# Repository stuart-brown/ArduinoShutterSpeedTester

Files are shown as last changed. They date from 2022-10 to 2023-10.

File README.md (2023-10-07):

# Arduino Shutter Speed Tester

A project to build a shutter speed tester using KY-008 laser diodes, ISO203 Laser Receiver & TFT display, all driven by an [Arduino Nano](https://docs.arduino.cc/hardware/nano). The code was developed in [VSCode](https://code.visualstudio.com/) using [Platform IO](https://platformio.org/). 
<br>

<div style="text-align: center;">
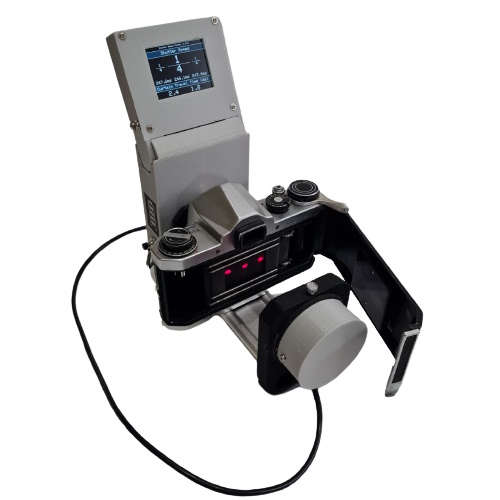
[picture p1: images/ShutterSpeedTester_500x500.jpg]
Shutter Speed Tester

</div>

## Status
This is a work in progress.
<br>

### What works:
* Measurement of shutter speeds & curtain travel times using 3 lasers and sensors
* Display time measurements & corresponding fractional shutter speeds  
* Display curtain travel times for 1st & 2nd curtain
* Calibration check
<br>

### To do:
* More content in this Readme, especially about calibration
* Ability to measure cameras like Barnack Leicas where you cannot access the rear of the shutter curtain.
* Finish project documentation: references, datasheets, circuit diagrams, etc. 
<br>

## Wiring Diagram
<div style="text-align: center;">
Wiring Diagram
</div>

## Components
### Arduino Nano
The heart of the system is an Arduino Nano.
<div style="text-align: center;">
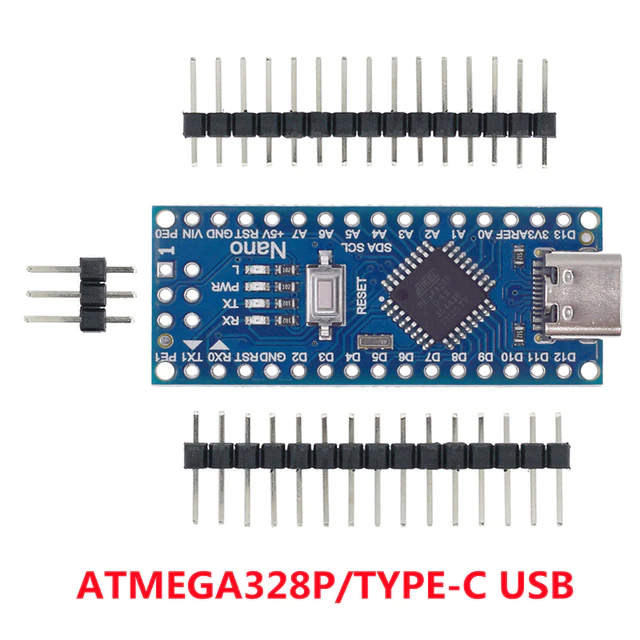
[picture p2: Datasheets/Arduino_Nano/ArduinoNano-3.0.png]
Arduino Nano

</div> 

### Laser Diode
The [KY-008 laser diode](https://arduinomodules.info/ky-008-laser-transmitter-module/) is a 650nm (red) laser, with an output power of 5mW. It can be bought as a standalone component or in module form (KY-008). The documentation says it can operate off of 5V, but reports on the internet say it will burn out quickly and a 39 ohm series resistor is needed to drop the voltage. The module version contains this resistor. This is what it looks like:
<div style="text-align: center;">
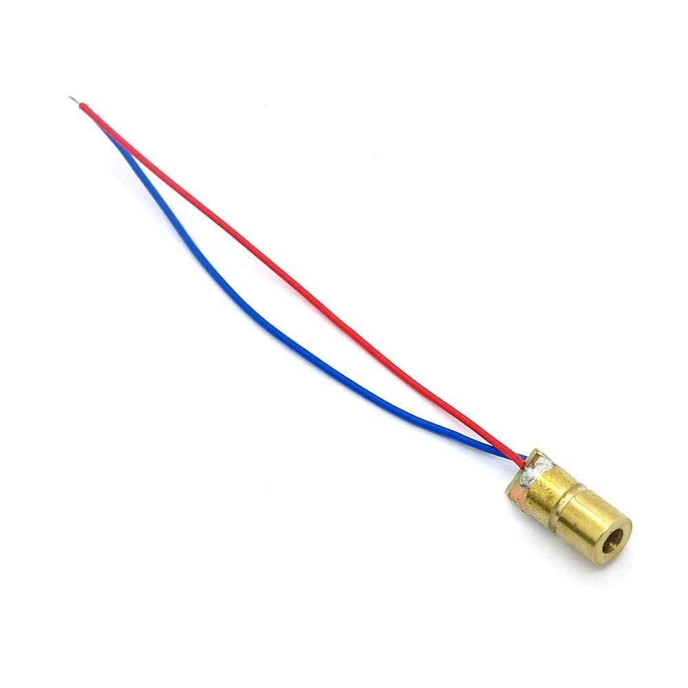
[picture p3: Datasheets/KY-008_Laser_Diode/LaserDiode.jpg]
Laser Diode (Standalone)

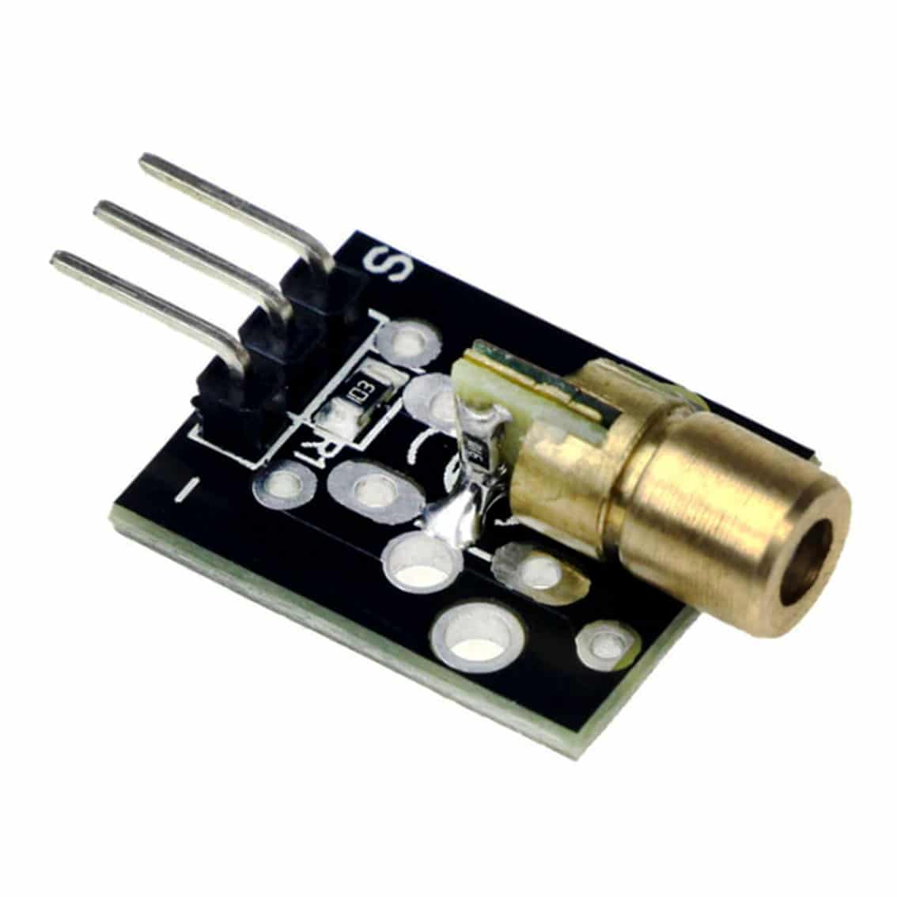
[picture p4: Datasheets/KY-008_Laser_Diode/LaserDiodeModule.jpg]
Laser Diode (Module)

</div>

### ISO203 Laser Receiver
It was difficult to find information on this component, but fortunately I came across a good [blog post](https://www.codrey.com/electronic-circuits/the-mysterious-laser-receiver-sensor-module/) covering it. It can be bought as a laser sensor module, or a standalone laser receiver. The module contains the components needed so you can simply plug it in to your Arduino. If you use the stand alone receiver, a pull-up resistor on the signal leg is needed.  This is what it looks like:
<div style="text-align: center;"> 
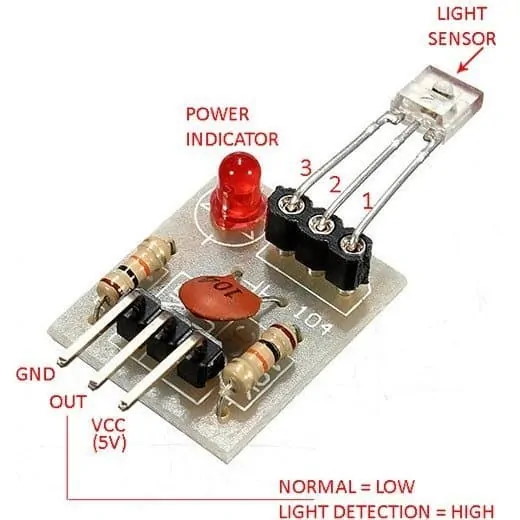
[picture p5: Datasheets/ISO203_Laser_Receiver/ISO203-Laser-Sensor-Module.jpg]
Laser Sensor Module

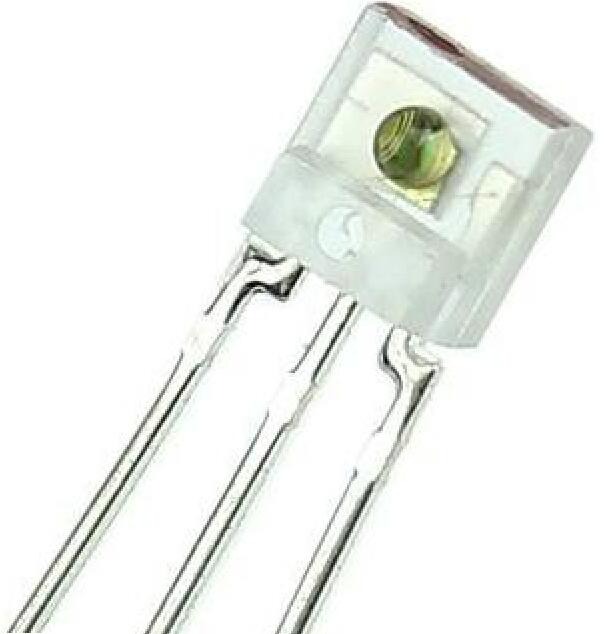
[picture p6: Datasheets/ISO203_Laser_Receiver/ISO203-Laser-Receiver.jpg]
Laser Receiver
 
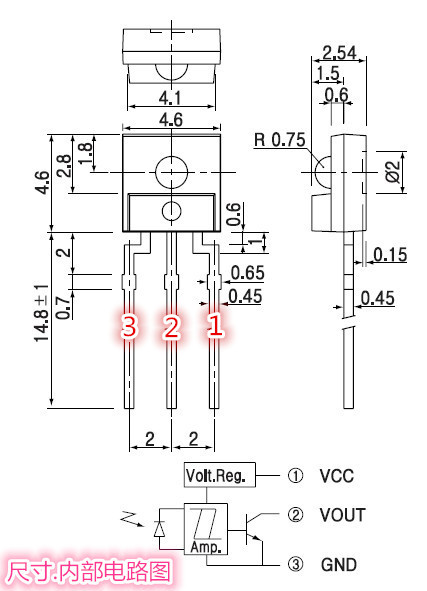
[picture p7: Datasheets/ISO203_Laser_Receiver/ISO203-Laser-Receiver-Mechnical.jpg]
Laser Sensor Module

</div> 

### LiPo Charger / Voltage Regulator Module
This module charges the LiPo battery and provides a constant regulated voltage to the Arduino and other electronics.
<div style="text-align: center;">
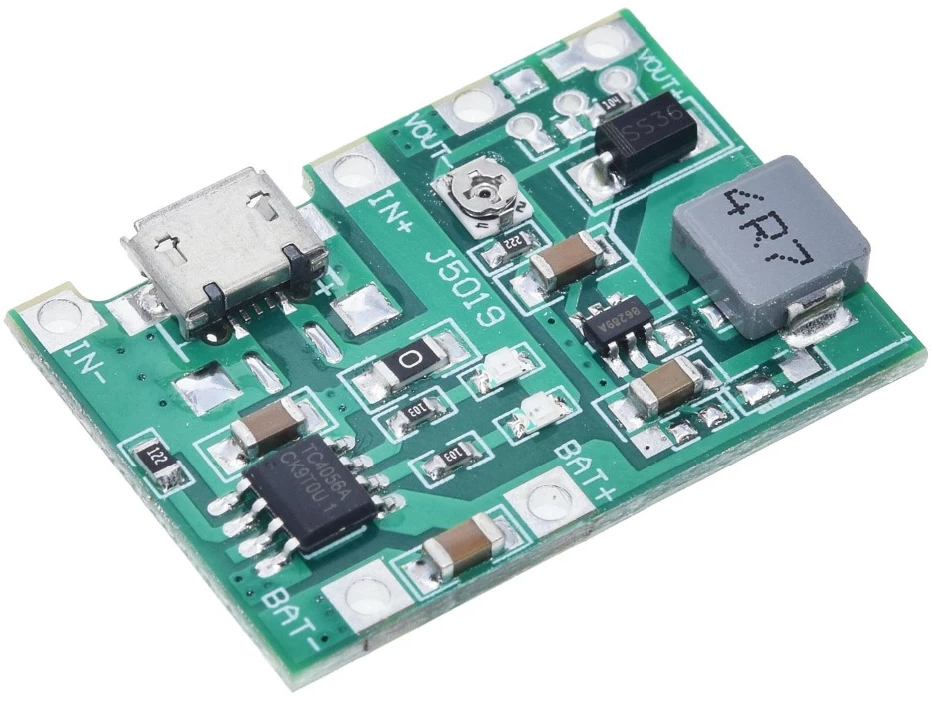
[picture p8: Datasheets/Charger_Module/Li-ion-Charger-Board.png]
LiPo Module

</div> 

### TXS0108E 8 Channel Level Shifter
The Arduino uses 5V logic levels, but the TFT display requires 3.3V levels. A level shifter is needed between the Arduino and the TFT display.
<div style="text-align: center;">
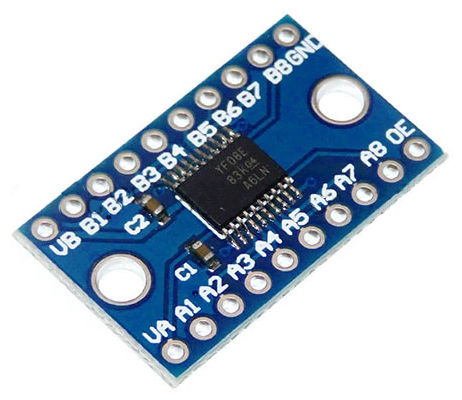
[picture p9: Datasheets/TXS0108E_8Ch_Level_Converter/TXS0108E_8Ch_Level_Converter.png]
TXS0108E Level Shifter

</div> 

### Display
The project started with a small 0.96 inch OLED display. But it was too small, so it was replaced by a larger TFT LCD.

##### 0.96" OLED 
 The code for the OLED display is still in the code base, it can be enabled by changing the line `#define USE_OLED 0` to `#define USE_OLED 1`. The OLED uses the i2c interface, and this is not shown on the wiring diagram.
<div style="text-align: center;">
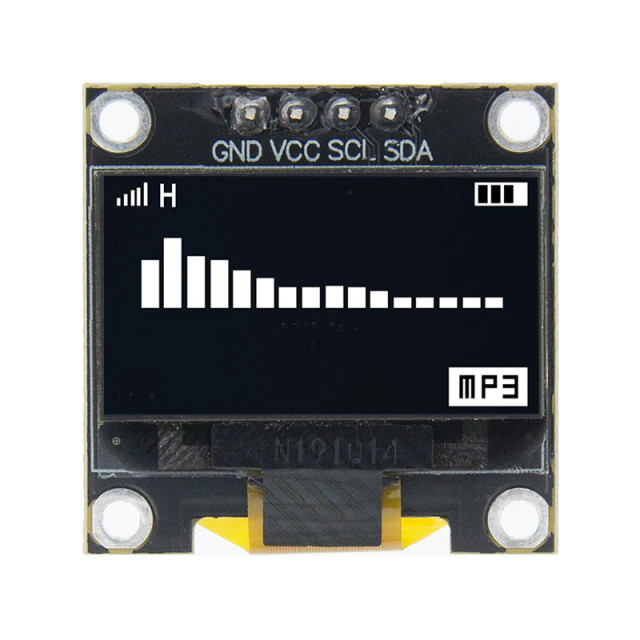
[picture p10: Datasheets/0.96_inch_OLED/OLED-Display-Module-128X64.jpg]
Small OLED Display

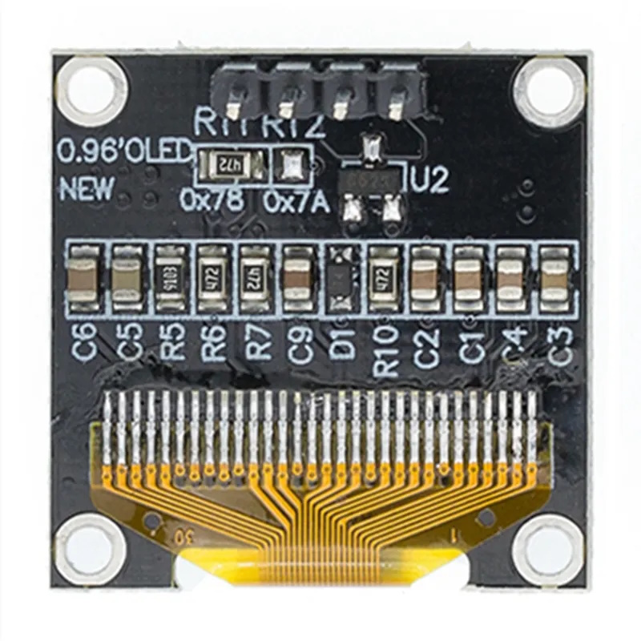
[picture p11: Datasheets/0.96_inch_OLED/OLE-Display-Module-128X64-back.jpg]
Small OLED Display
  
</div> 

##### TFT LCD Display
The tester was built using a 2.2 inch TFT display with 240x320 resolution and ILI9341 driver chip. A smaller or larger display could be used as long as the resolution and driver are the same. The display used had a SD Card slot on the back, this was was not used.
<div style="text-align: center;">
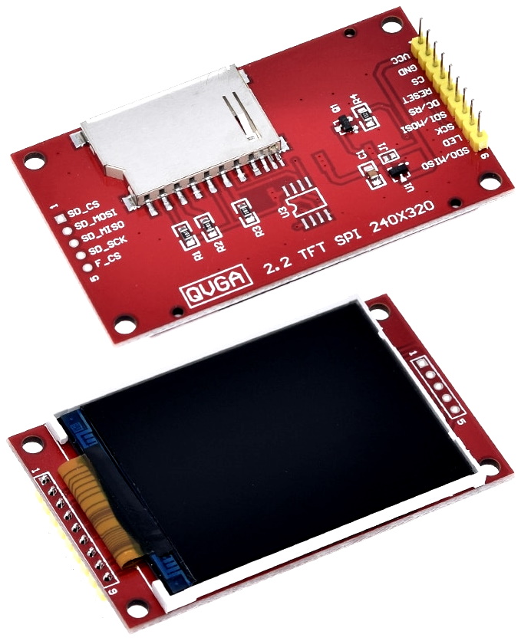
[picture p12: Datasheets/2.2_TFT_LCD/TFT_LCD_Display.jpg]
TFT LCD Display

</div> 
<br>

### Other components
Rocker switch, USB charge connector and a 550mAh 13400 battery recovered from a disposed vape. The second version added a battery indicator and normally open momentary push button to connect it to the battery to show the battery level.
<div style="text-align: center;">
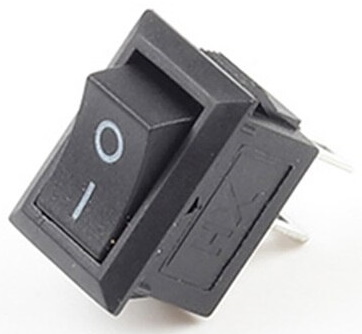
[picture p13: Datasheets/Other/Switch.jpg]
Switch

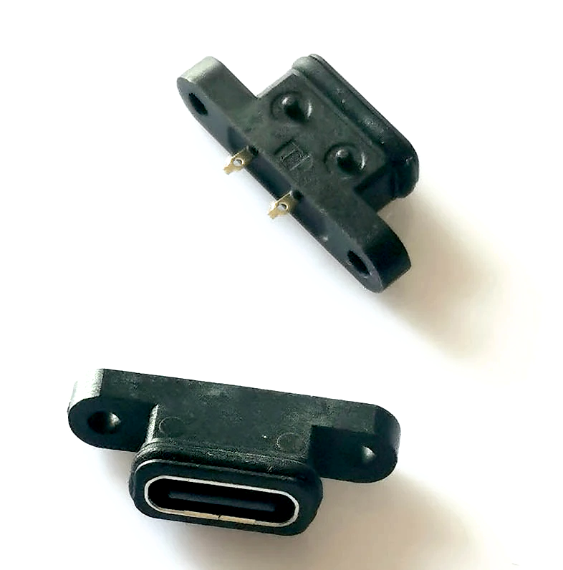
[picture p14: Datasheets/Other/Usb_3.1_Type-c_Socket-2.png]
USB Power Socket

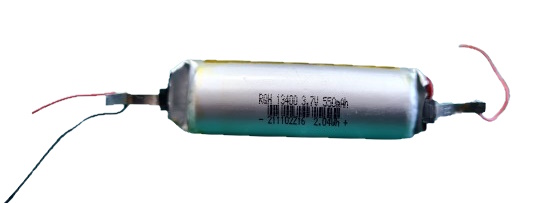
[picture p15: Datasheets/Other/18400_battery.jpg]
18400 Battery

</div>
<div style="text-align: center;">
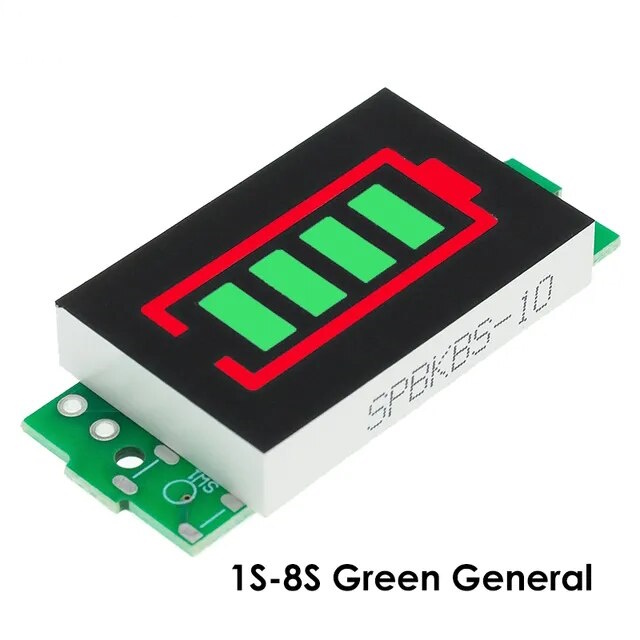
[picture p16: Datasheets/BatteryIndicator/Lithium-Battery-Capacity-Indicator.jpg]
Battery Indicator

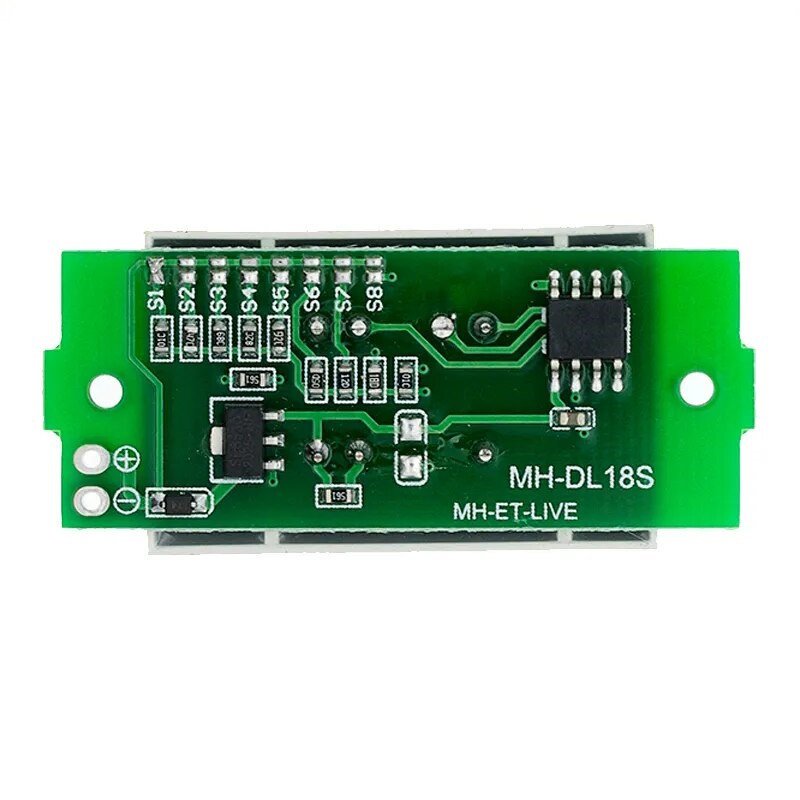
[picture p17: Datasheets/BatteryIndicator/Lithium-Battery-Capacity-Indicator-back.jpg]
Battery Indicator

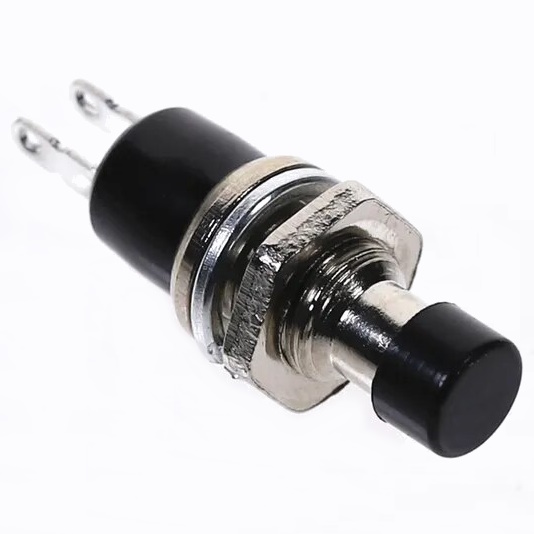
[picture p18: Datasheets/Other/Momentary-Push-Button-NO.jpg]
NO Momentary Push Button

</div>

<br>

## Mechanicals
The mechanical build is based on a Pangor M42 macro bellows, paired with 3D printed parts. The design could be adjusted to work with any bellows. 

The bellows was disassembled to remove the expanding bellows and only the rail and end housings were used. This forms the chassis to which the 3D printed parts attach. There are two housings attached, one at either end of the chassis. There is one for the laser detectors and electronics, and another for the laser diodes. Both the laser diode and laser sensor housings are circular and can be rotated to allow the sensors and lasers to be aligned. Using a macro bellows as the chassis provides a stable platform that makes sensor and diode alignment easy and keeps them aligned when sliding further apart or closer together to accommodate different cameras.

The laser detectors are kept close to the electronics to minimise the chances of false detects due to noise. 

Since the laser diodes only need power to turn them on, noise is not an issue, and they are on the end of a cable that connects them to the electronics box.

<div style="text-align: center;">
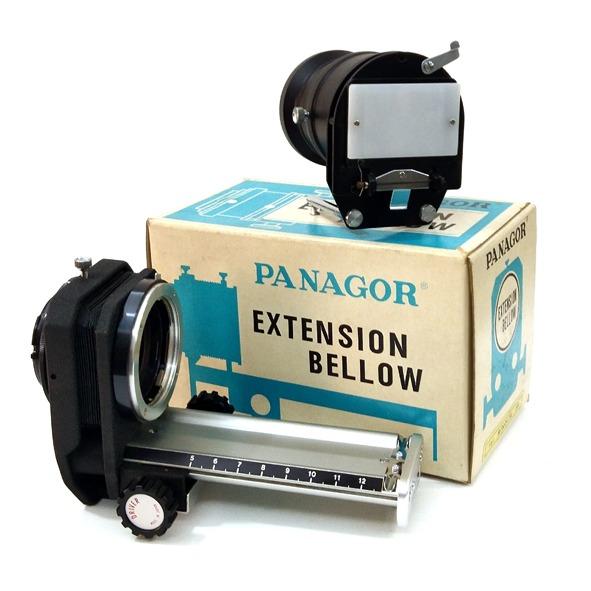
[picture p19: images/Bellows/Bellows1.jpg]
Pangor M42 Macro Bellows

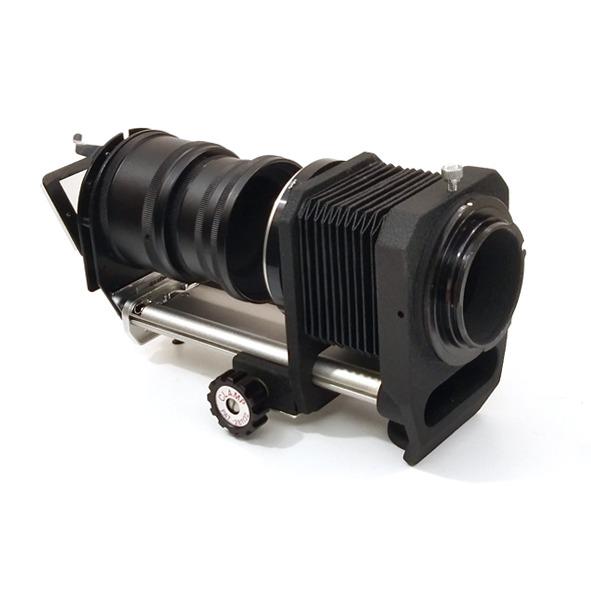
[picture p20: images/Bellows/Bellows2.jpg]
Pangor M42 Macro Bellows

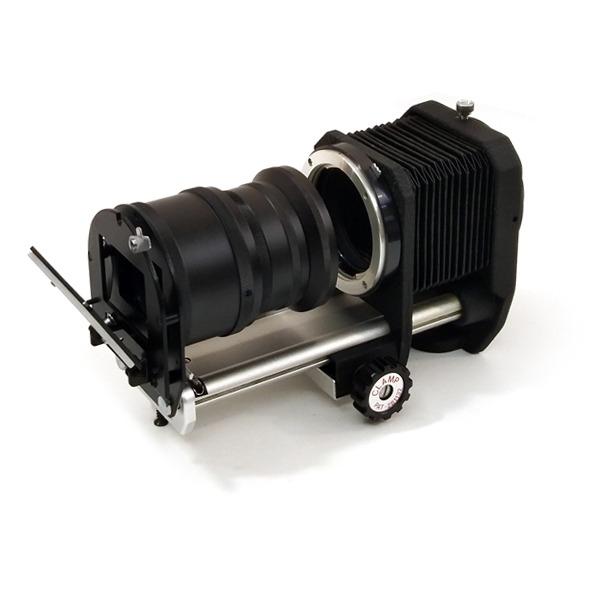
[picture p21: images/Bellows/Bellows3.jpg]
Pangor M42 Macro Bellows

</div>

Construction photos showing details of the assembly are shown below. More photographs are available in the images directory of the project.

### Version 1
<div style="text-align: center;">
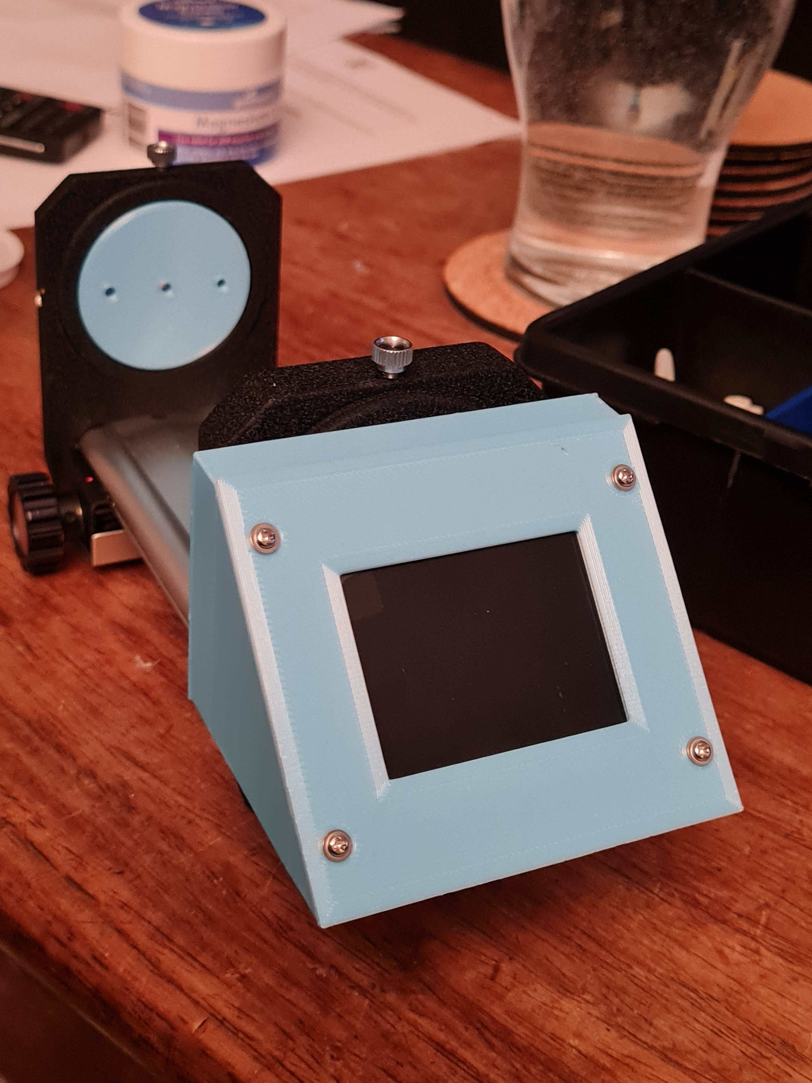
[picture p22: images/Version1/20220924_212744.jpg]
Version 1

</div>
<br>

Version 1 of the housing was printed using blue PLA and coloured black using a liquid shoe dye. Once built it became evident that there were a few deficiencies in the design:
1) The laser diode holders were printed with three small screws at 120 degree intervals. The idea being that the screws could be used to hold the laser diodes and adjusted to aim the diode at the sensor. This idea did not work.
2) The screen was awkward to read, it needed to face the other direction.

#### Laser diodes
An old USB cable with a broken connector was used to connect the laser diodes. Both end connectors were cut off and each laser diode wired to one wire connected to an IO pin on the Arduino. A common ground was wired on the 4th wire. The current limiting resistors are soldered inline, directly between the diode and wire, covered in heat shrink to prevent shorting. A simple knot in the cable serves as strain relief.

<div style="text-align: center;">
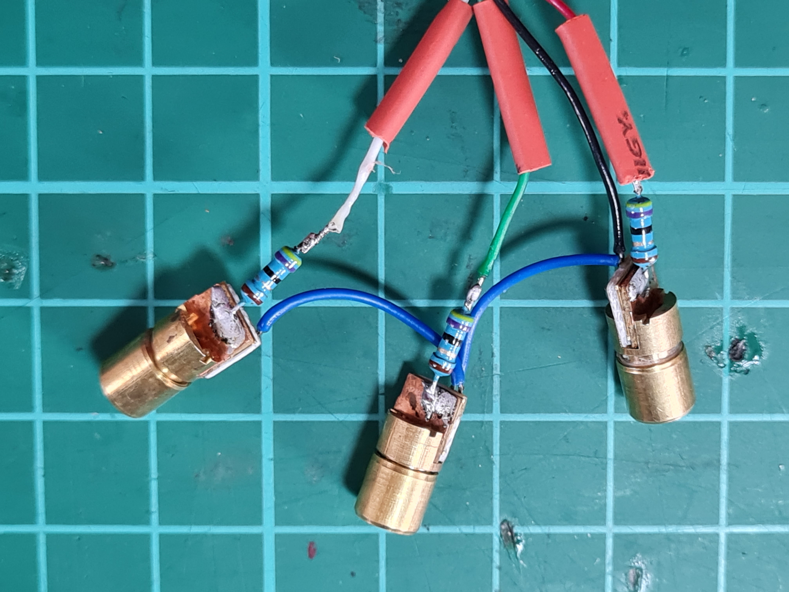
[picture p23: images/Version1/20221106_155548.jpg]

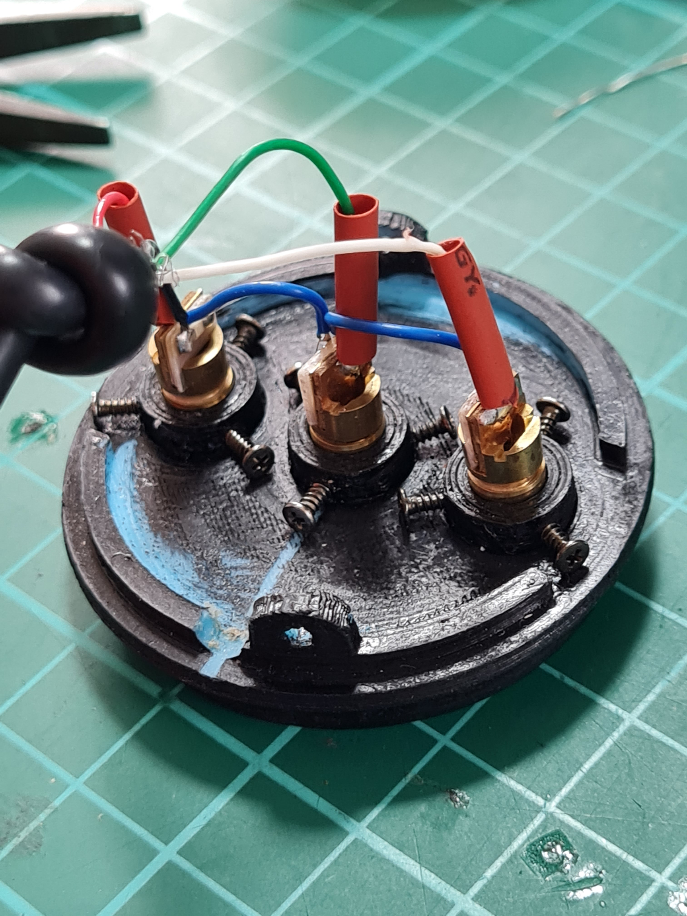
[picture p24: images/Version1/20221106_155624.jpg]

</div>

#### Laser sensors
Each laser sensor is soldered onto a small piece of [stripboard](https://en.wikipedia.org/wiki/Stripboard) with its 10kΩ pull up resistor. They fit into specially shaped recesses on the 3D printed part and are held in place by a plate that clamps down on the back of them. They are wired with common ground and power lines, and each has its own signal line to an IO pin on the Arduino.

<div style="text-align: center;">
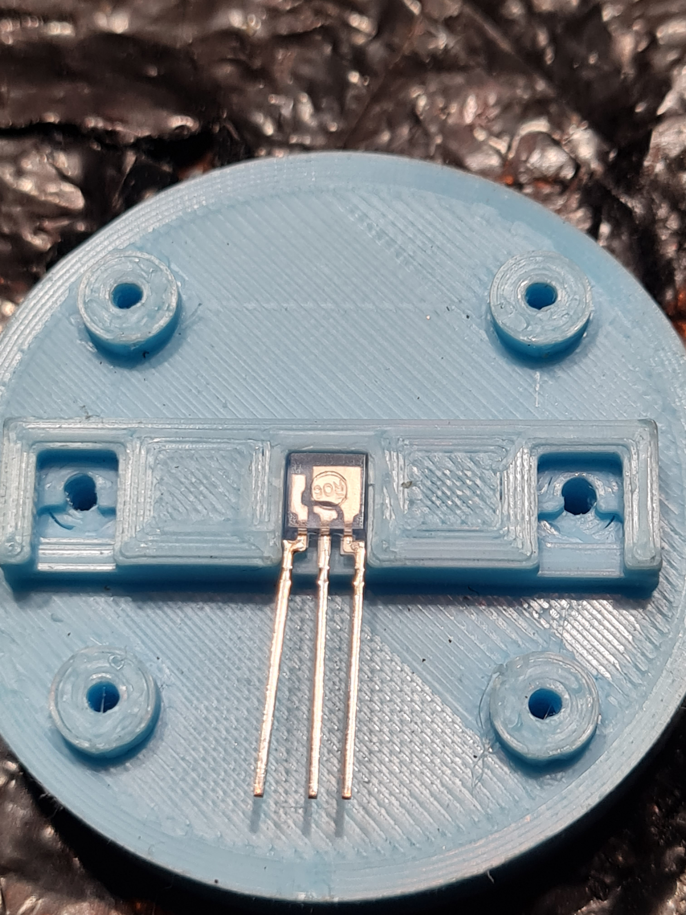
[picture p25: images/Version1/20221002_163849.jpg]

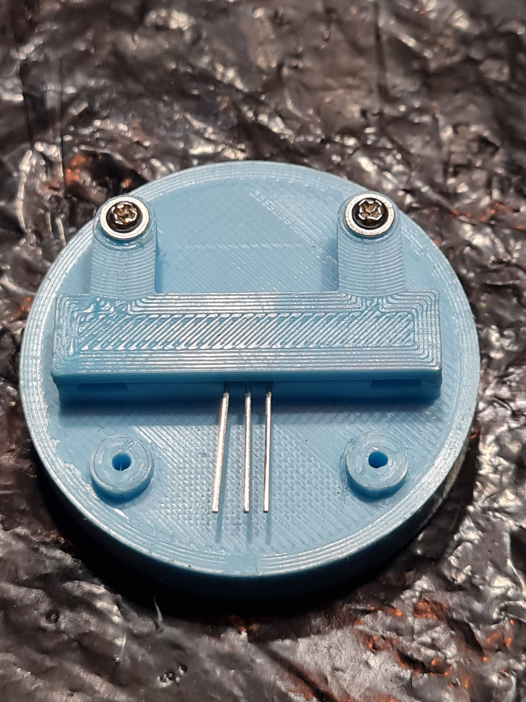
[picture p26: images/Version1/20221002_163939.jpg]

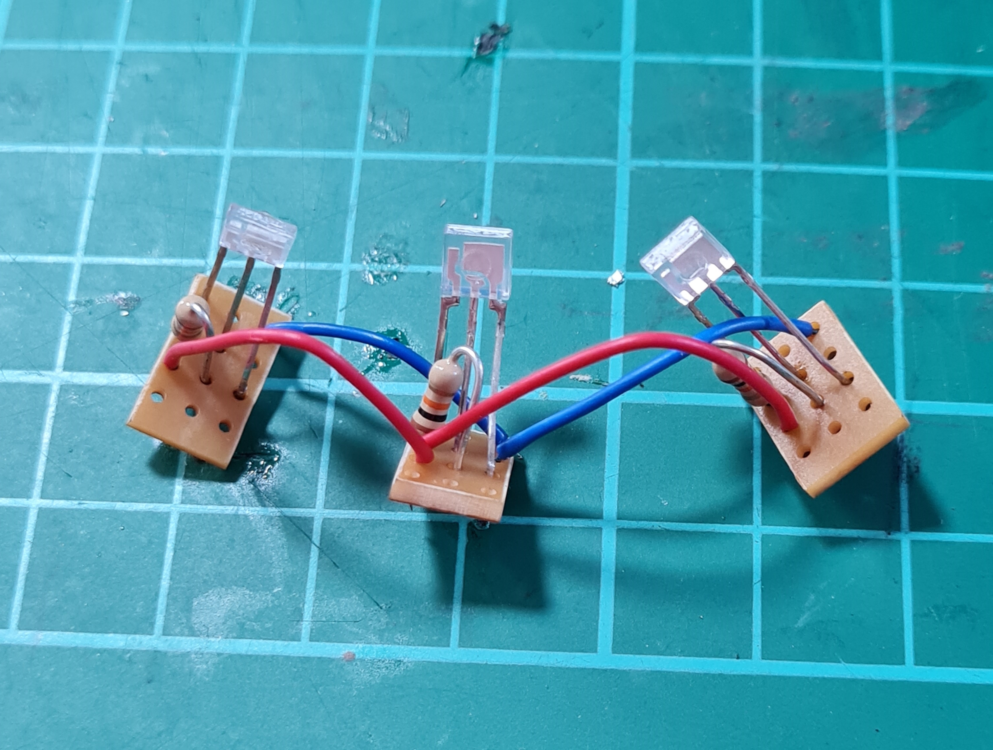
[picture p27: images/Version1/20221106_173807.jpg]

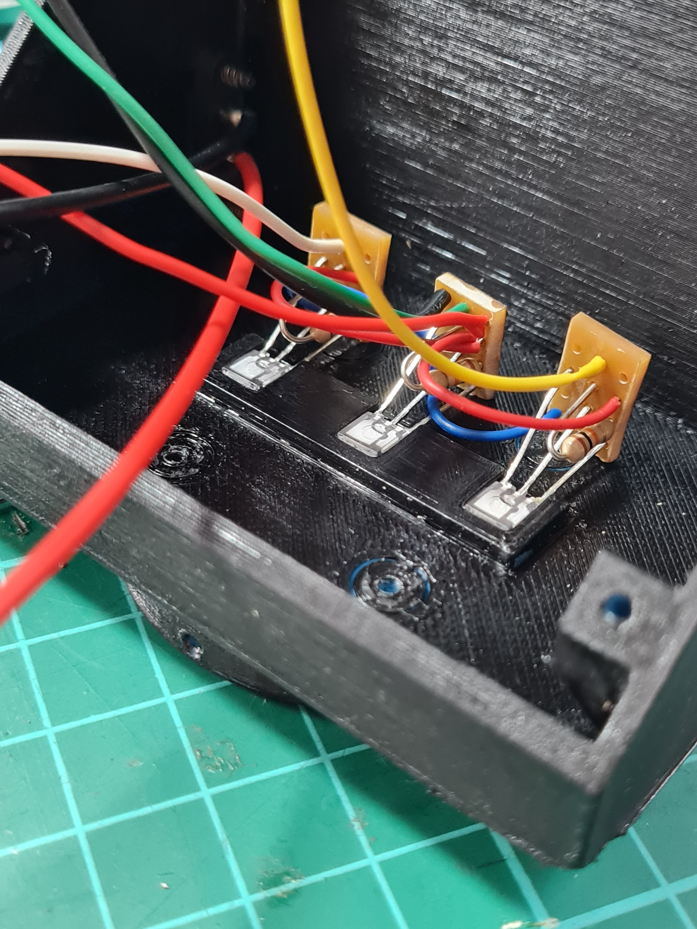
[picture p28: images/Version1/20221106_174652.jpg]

</div>

<br>

#### Display and electronics
The display and electronics are housed in a box that mounts to the laser detector housing. It was rather tight in this version.

<div style="text-align: center;">
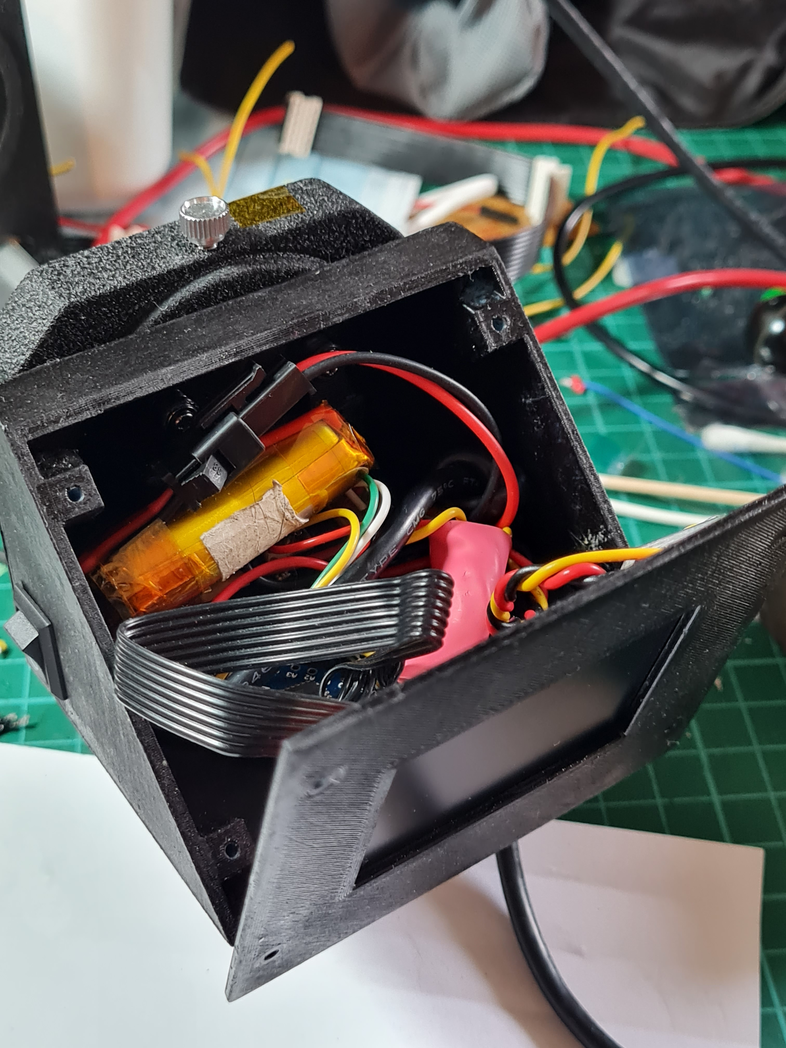
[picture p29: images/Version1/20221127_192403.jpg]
Display and electronics

</div>

#### Alignment
The macro bellows has two thumb screws, one on each side (red arrows in image below). The laser detector housing has a 3D printed "dimple" in the circular ring at the "12 o'clock" position that the thumb screw screws into to align it and stop it rotating. The laser diode holder does not have any "dimples", it can be rotated to align the laser diodes and sensors (yellow arrow in image below), then the thumb screw is screwed down to hold it in place.  

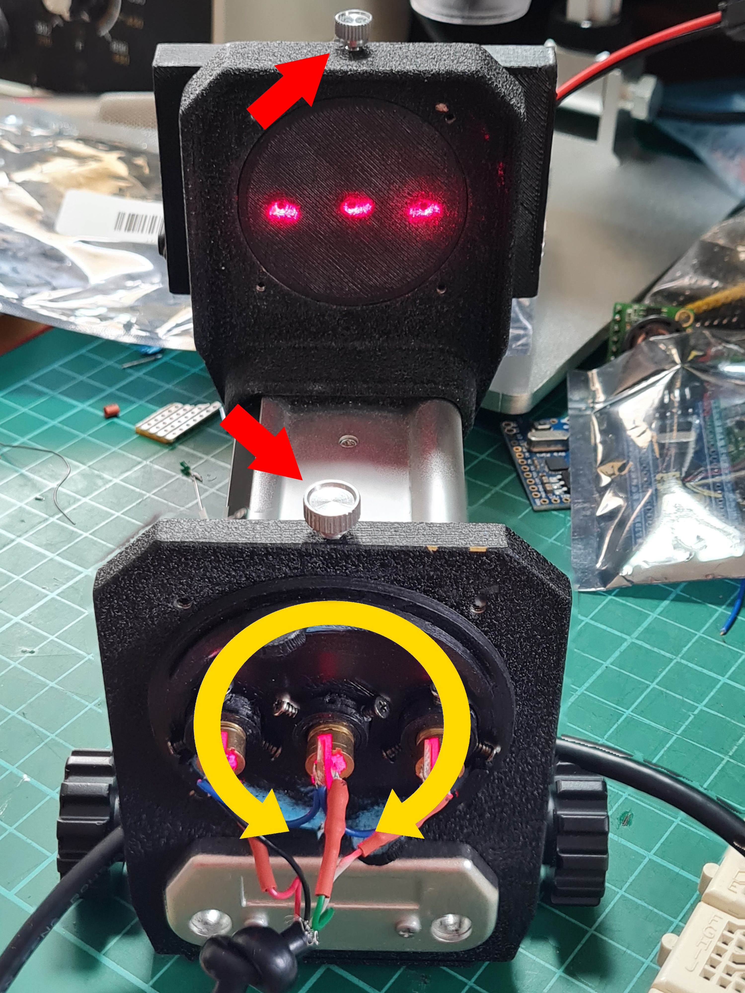
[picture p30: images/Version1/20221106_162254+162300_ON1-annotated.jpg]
Alignment


### Version 2
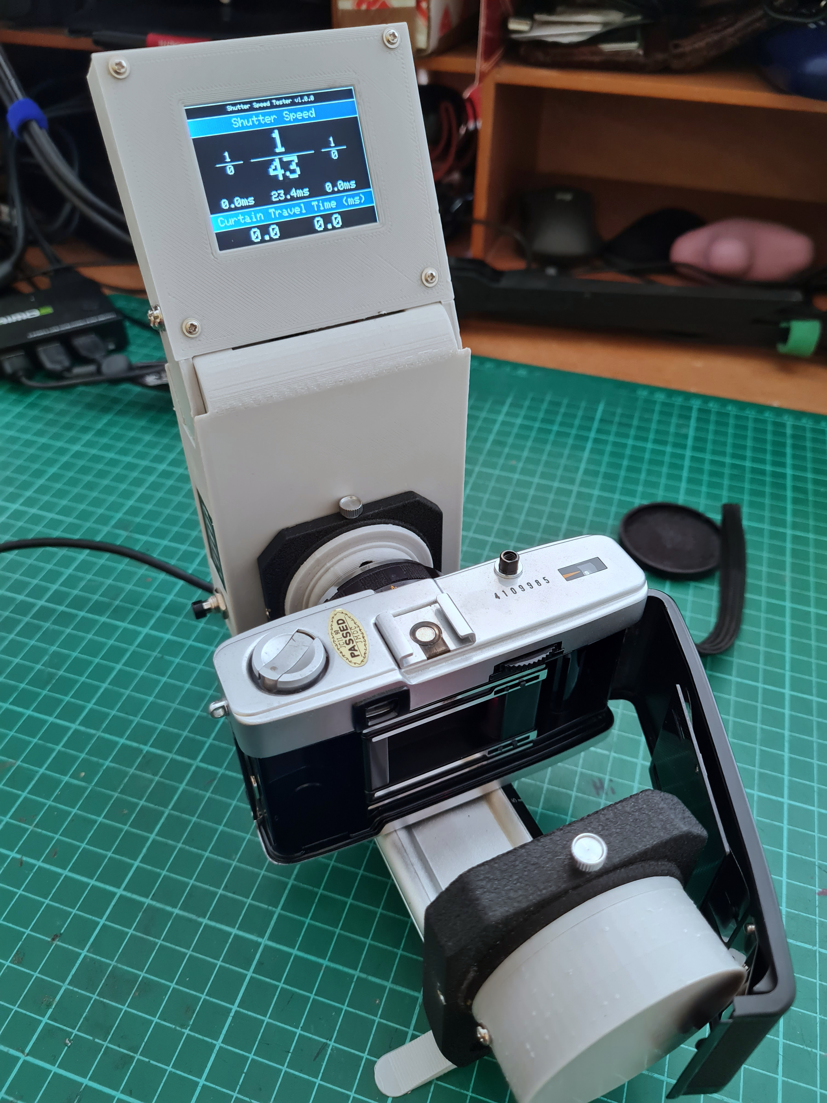
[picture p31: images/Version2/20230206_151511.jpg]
Version 2

<br>

Version 2 of the housing corrected the issues with the first design and added a battery meter and some small improvements. A 3D printed foot was also added for stability. 

Version 2 also has some problems that will be corrected in the next version: 
 1) The display was designed to be adjustable, this turned out to be not necessary and just added complication.
 2) The housing could be made smaller.

#### Battery Meter
The battery meter turned out to be much larger than anticipated and the bottom housing needed to be made much larger. This did help with the tight fit compared to version 1, there is much more space and the electronics fit in much easier.

<div style="text-align: center;">
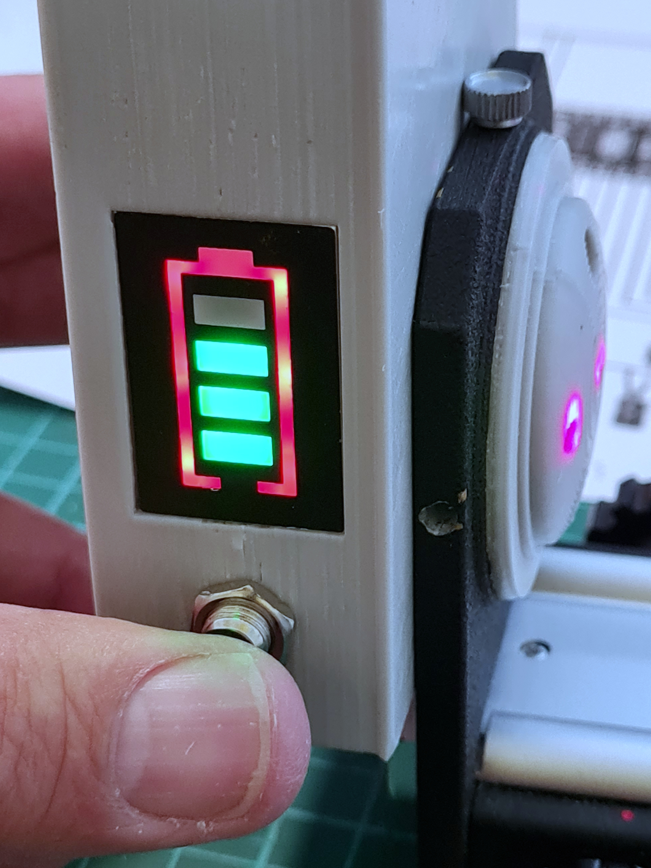
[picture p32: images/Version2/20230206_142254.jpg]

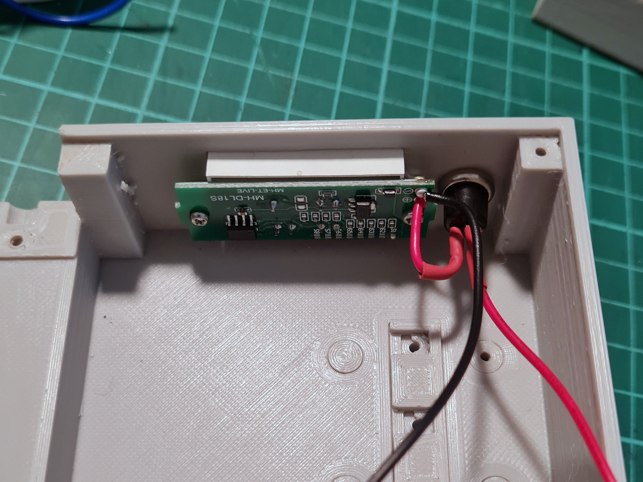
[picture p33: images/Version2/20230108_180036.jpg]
  
  </div>

#### Laser Diodes
The laser diodes are now housed in a ball joint, with each ball clamped down by a small rectangular block. This allow each laser to be adjusted and aimed at the corresponding laser sensor individually. The knot in the cable has been replaced by a proper cable strain relief block that clamps the cable.

<div style="text-align: center;">
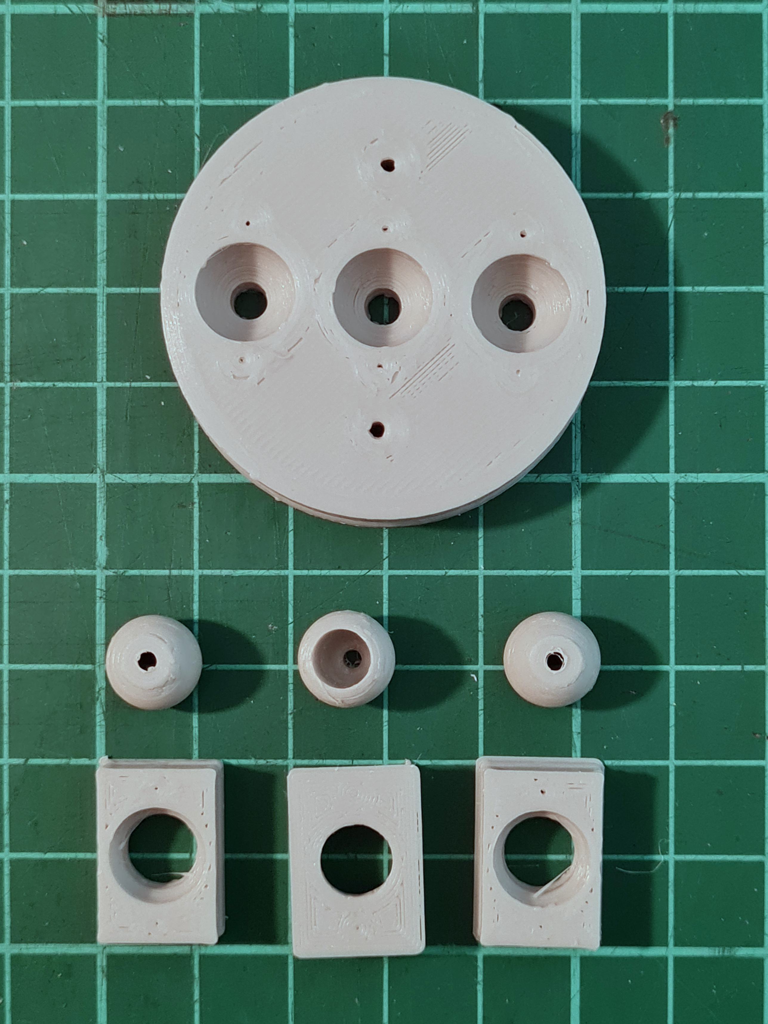
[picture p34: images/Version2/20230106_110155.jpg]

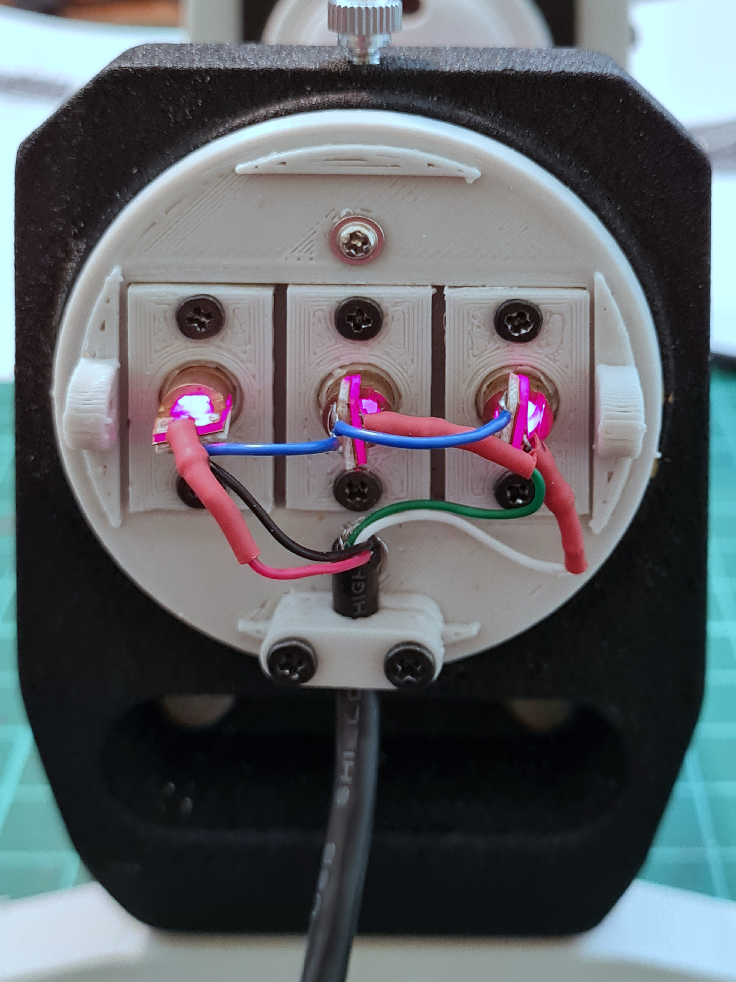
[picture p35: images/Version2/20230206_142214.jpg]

</div>
<div style="text-align: center;">
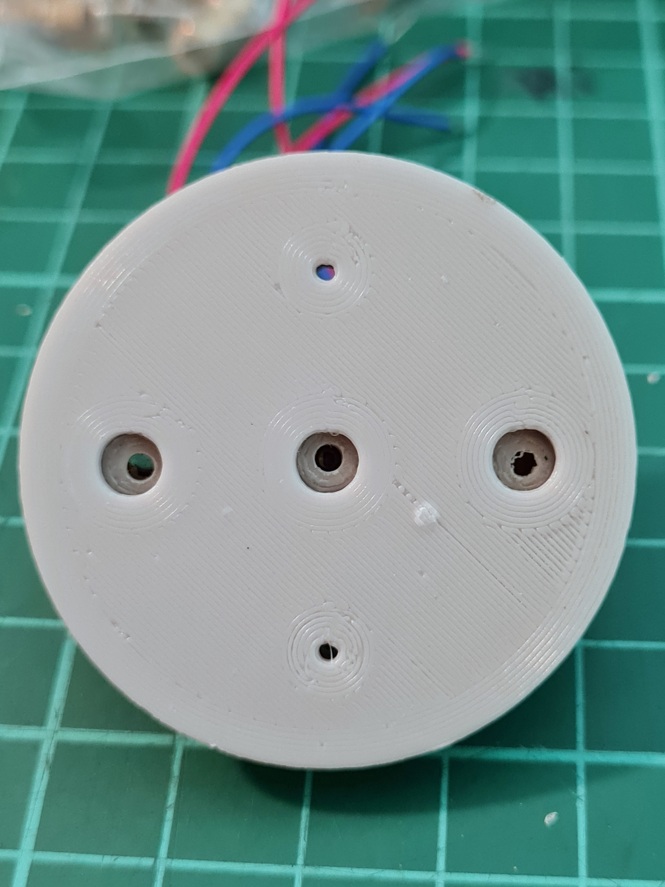
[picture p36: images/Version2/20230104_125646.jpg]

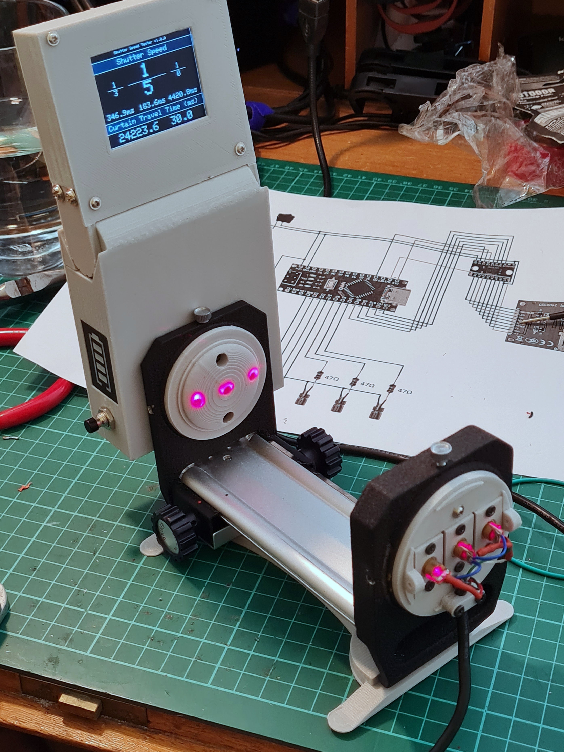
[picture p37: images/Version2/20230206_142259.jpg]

</div>

#### Camera Alignment Cone
A shallow cone screws onto the front of the laser detector housing. The camera lens mount ring is pushed onto this cone, and it helps to align the camera with the tester. 

<div style="text-align: center;">
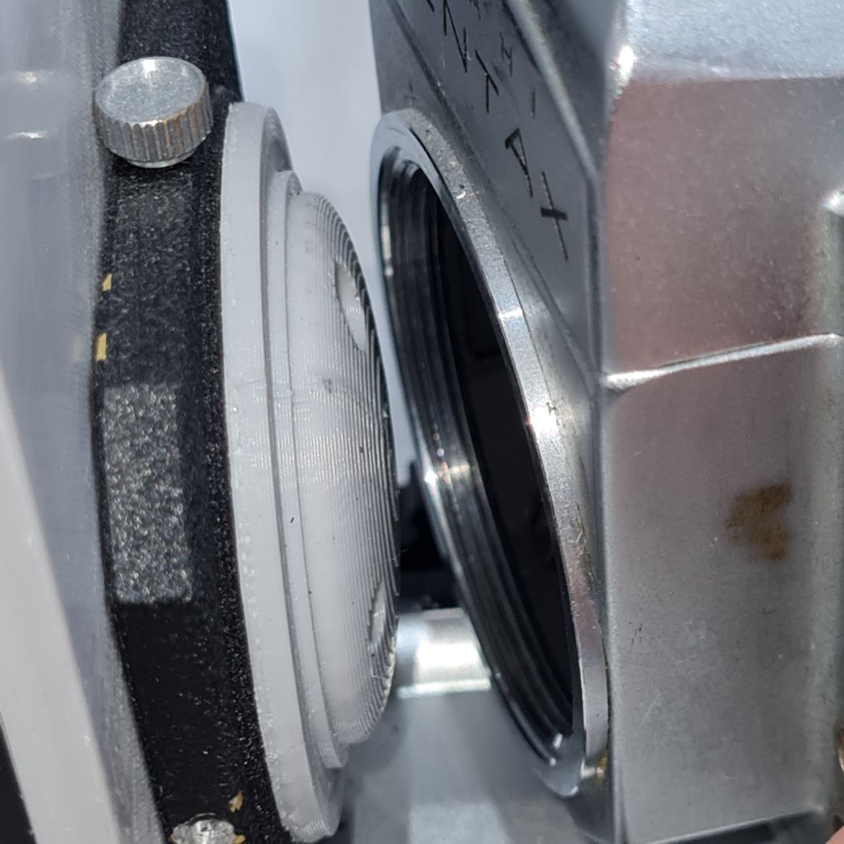
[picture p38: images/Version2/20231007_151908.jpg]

</div>

#### Foot
A 3D printed foot is bolted onto the tripod mount on the bottom of the bellows housing to improve stability.
<div style="text-align: center;">
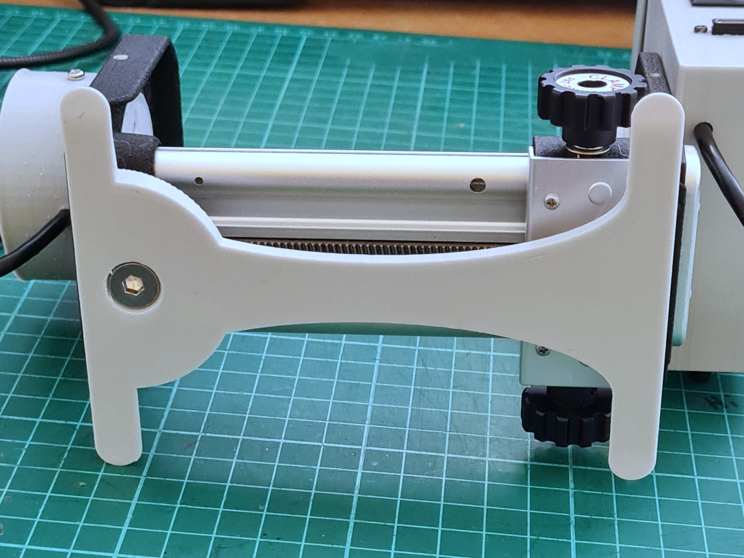
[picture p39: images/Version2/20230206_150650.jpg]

</div>
<br>

## 3D Printed Parts
The STL files for the 3D Printed parts can be found in the STL folder in the repository

# Getting Going
* Download and setup VSCode and PlatformIO. See https://dronebotworkshop.com/platformio/
* Open the project in VSCode
* Build using PlatformIO
<br>

# Calibration
Calibration was done using a calibration device consisting of a STM32 Nucleo-F303RE development board driving a KY-008 laser diode. This pulses the laser at regular intervals, the width of the pulse can be changed by pressing the 'user' button on the dev board. The width of the ON pulses was measured using a digital storage oscilloscope to confirm their accuracy.

The STM32 calibration device was then use to illuminate the laser receiver on the shutter speed tester to check that the tester measured and displayed the correct time.

The rise and fall times of the laser detector were also checked using the oscilloscope.

Details of the calibration device can be found in the following repo https://github.com/stuart-brown/ShutterSpeedTesterCalibrator

<br>

# References and Interesting Reading:
* [ISO 516:2019 Camera shutters — Timing — General definition and mechanical shutter measurements](https://www.iso.org/standard/70966.html) - This is __*the standard*__ for testing shutter speeds. You need to buy the standard, but there are various previews available online, enough to glean useful information from.

* [The Way to Modern Shutter Speed Measurement Methods A, Historical Overview, by Gyula Simon, Gergely Vakulya, and Márk Rátosi](https://www.mdpi.com/1424-8220/22/5/1871) - A paper that delves into various methods to measure shutter speeds.

* [National Camera, Technician Course, Testing Shutter Speeds](https://learncamerarepair.com/downloads/pdf/NatCam-Shutter-Test-Guide.pdf)

* [Charts of Nominal, and Precise Actual camera
Shutter speed, f stop and ISO goal values](https://www.scantips.com/lights/math.html) &  [Camera Math of photography settings and EV](https://www.scantips.com/lights/fstop2.html) - These pages contain an enlightening discussion about 'Nominal' vs 'Accurate' values and the maths behind cameras.

<br>
<br>

# Some other shutter speed testers & projects
* http://forum.mflenses.com/the-shutter-speed-meter-project-t11387.html

* https://www.pentaxforums.com/forums/8-film-slrs-compact-film-cameras/409300-optical-measurements-pentax-me-super-shutter-speed.html

* https://www.pentaxforums.com/forums/173-general-photography/359823-true-shutter-speeds-compared-nominal-shutter-speeds-actual-measurements.html

* [Laser Shutter Tester](https://community.element14.com/challenges-projects/project14/makingtime/b/blog/posts/laser-shutter-tester)

* [VFMOTO camera shutter tester](https://www.ebay.com/usr/vfmoto) - A commercial product sold on EBay

* [Film Camera Tester](https://github.com/srozum/film_camera_tester/wiki) - This one is available as a DIY kit on or assembled from [Tindie](https://www.tindie.com/products/srozum/film-camera-tester/)

* [Speed tester](https://github.com/cameradactyl/Shutter-Timer) by cameradactyl - A project very similar to this one :)

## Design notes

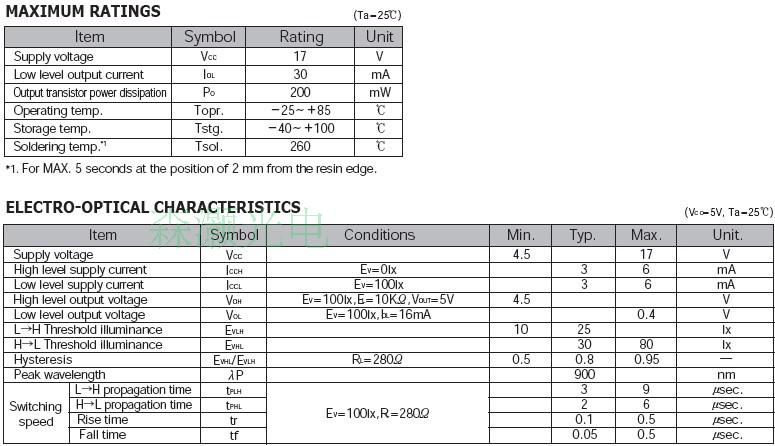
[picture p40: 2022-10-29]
Datasheets/ISO203_Laser_Receiver/ISO203-Laser-Receiver-Specification-1.jpg

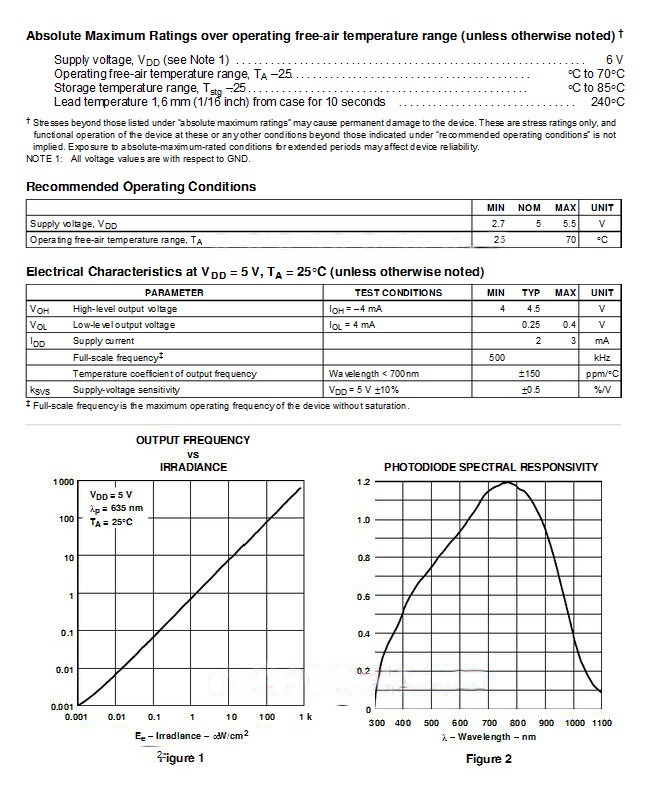
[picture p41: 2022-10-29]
Datasheets/ISO203_Laser_Receiver/ISO203-Laser-Receiver-Specification-2.jpg

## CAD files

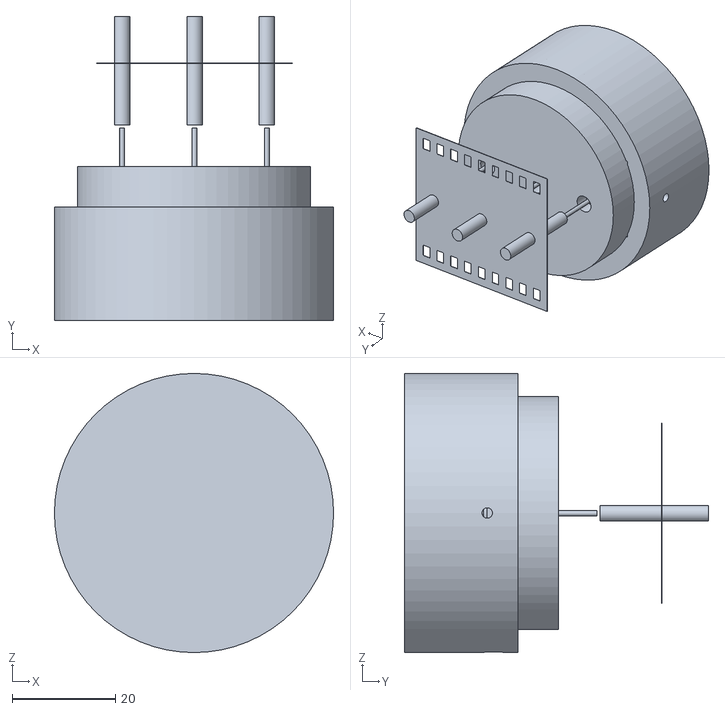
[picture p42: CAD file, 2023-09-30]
STL/Version2/Laser Diode Holder v2 Assembly.stl
54.0 x 58.8 x 54.0

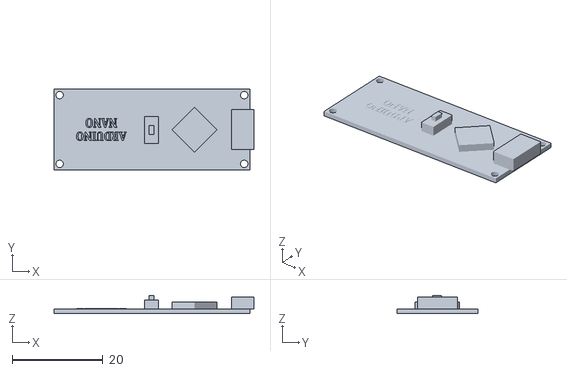
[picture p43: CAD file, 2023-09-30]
STL/ElectronicComponents/Arduino Nano.stl
44.1 x 17.8 x 4.00

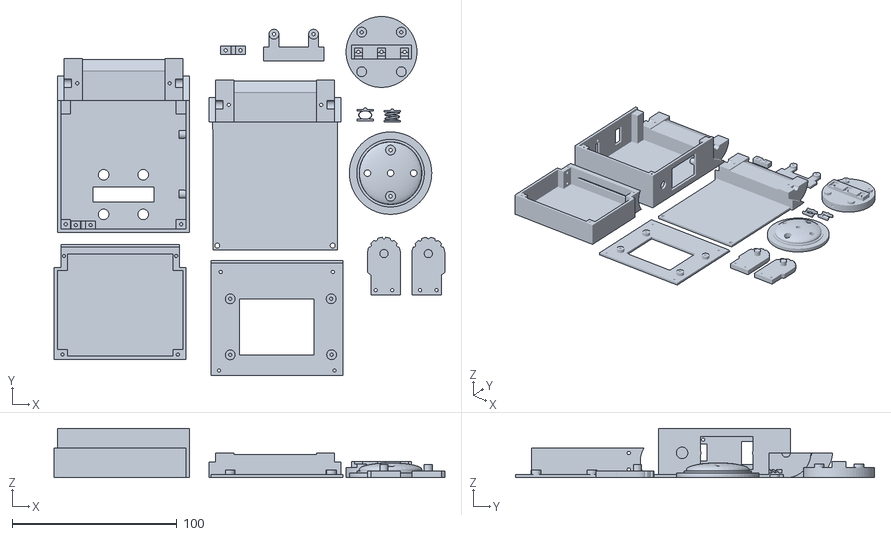
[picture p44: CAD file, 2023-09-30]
STL/Version2/Electronics Box v2.stl
236.9 x 217.7 x 30.0

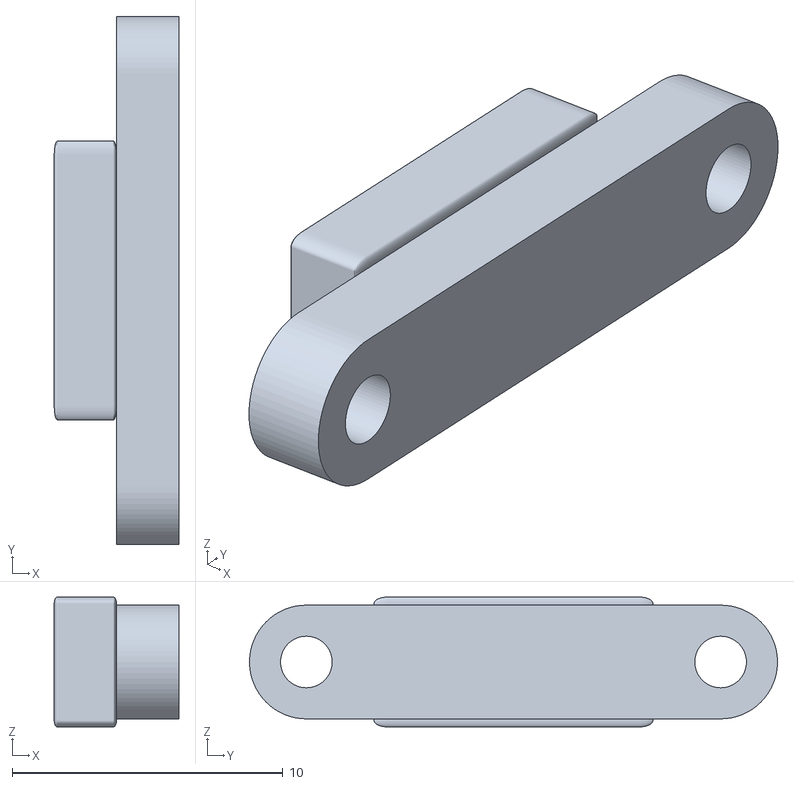
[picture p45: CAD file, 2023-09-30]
STL/ElectronicComponents/USB-C Charging Connector.stl
4.60 x 19.5 x 4.80

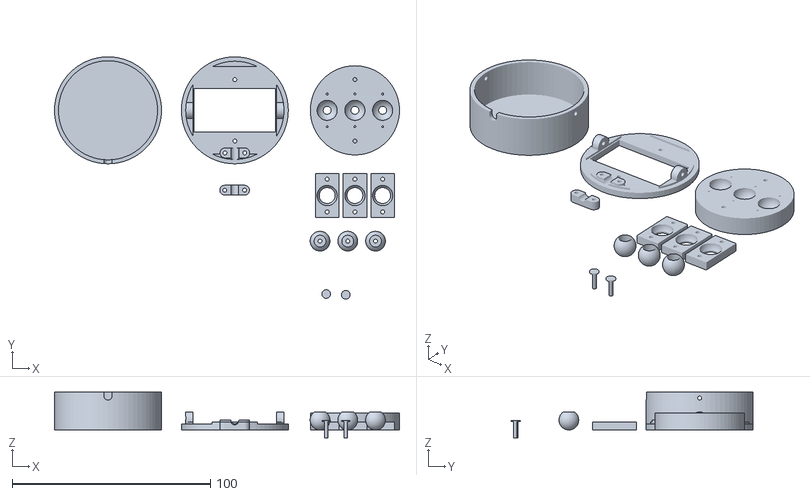
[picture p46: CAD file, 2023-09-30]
STL/Version2/Laser Diode Holder v2.stl
174.1 x 122.3 x 23.1

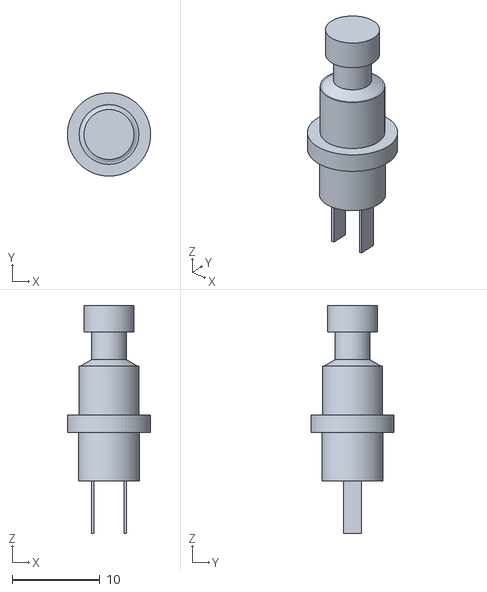
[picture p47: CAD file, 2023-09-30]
STL/ElectronicComponents/Push Switch.stl
9.50 x 9.50 x 26.0

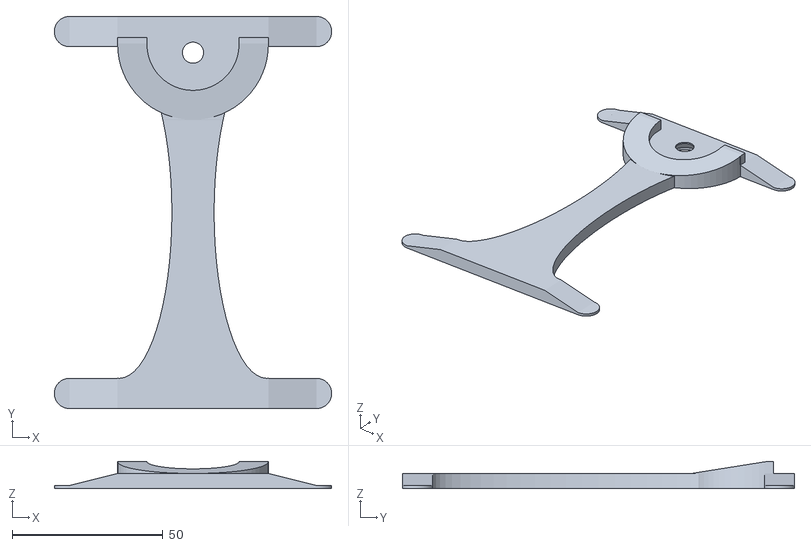
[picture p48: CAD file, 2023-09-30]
STL/Version2/Shutter Tester Stand.stl
92.0 x 130.0 x 9.00

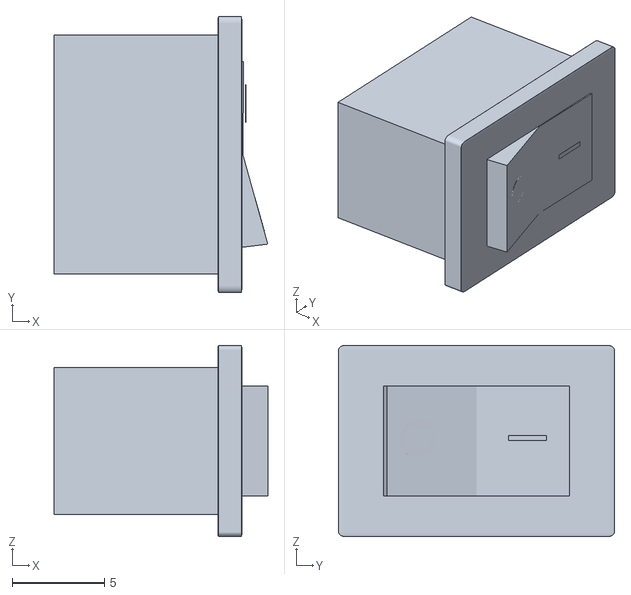
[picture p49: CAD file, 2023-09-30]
STL/ElectronicComponents/Rocker Switch.stl
11.6 x 15.0 x 10.4

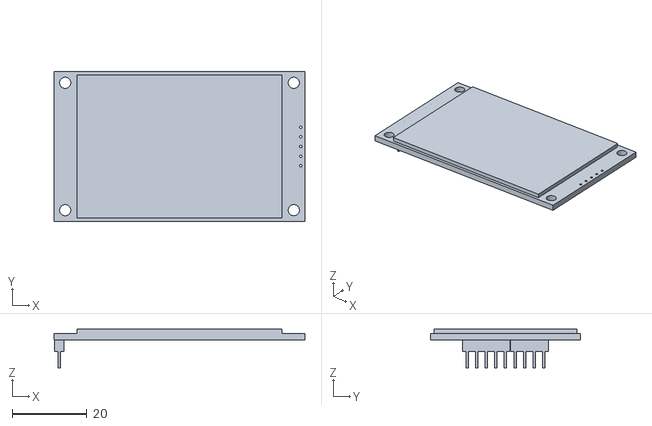
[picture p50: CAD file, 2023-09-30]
STL/ElectronicComponents/2.2 inch TFT Display.stl
67.2 x 40.1 x 10.3

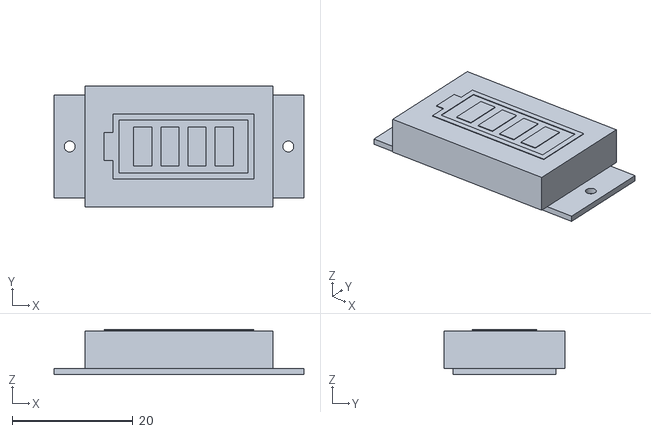
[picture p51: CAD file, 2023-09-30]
STL/ElectronicComponents/Battery Meter.stl
41.4 x 20.0 x 7.50

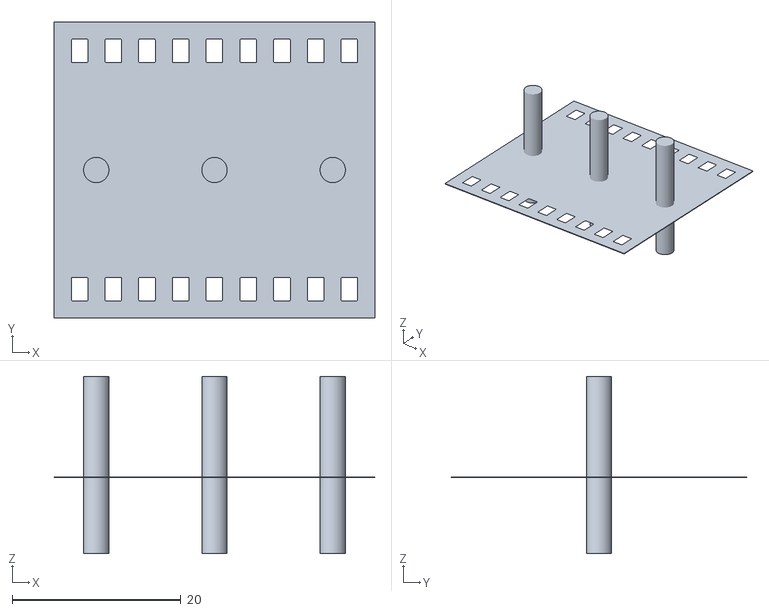
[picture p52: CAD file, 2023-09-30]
STL/ElectronicComponents/35mm Film Frame.stl
38.0 x 35.0 x 21.0

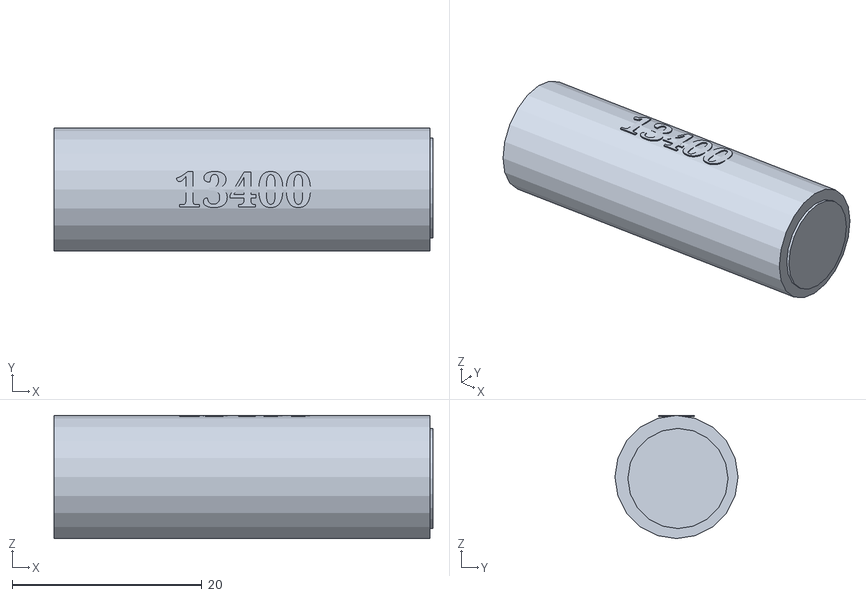
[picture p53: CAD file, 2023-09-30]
STL/ElectronicComponents/13400 attery.stl
40.0 x 13.0 x 13.0

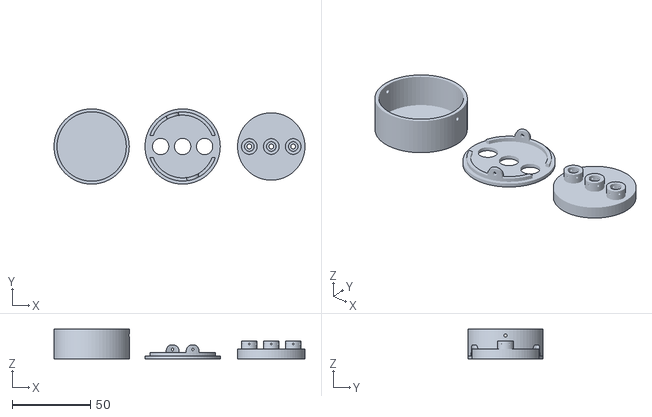
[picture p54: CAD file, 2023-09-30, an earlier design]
STL/Version1/Laser Diode Holder.stl
160.0 x 48.0 x 19.0

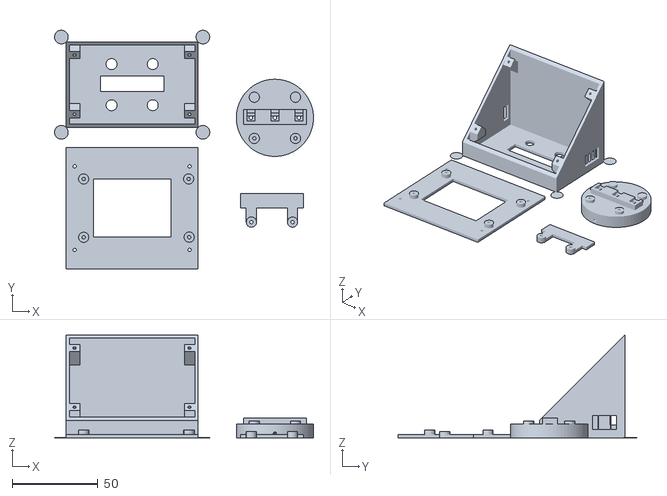
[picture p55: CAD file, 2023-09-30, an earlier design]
STL/Version1/Laser Detector Holder & Electronics Box.stl
150.9 x 139.0 x 60.0

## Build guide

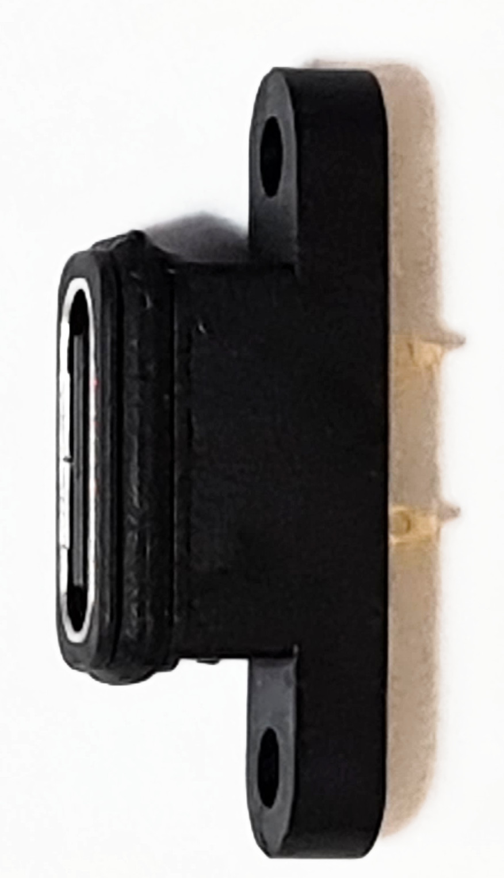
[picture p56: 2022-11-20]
WiringDiagram/USBConnector.jpg

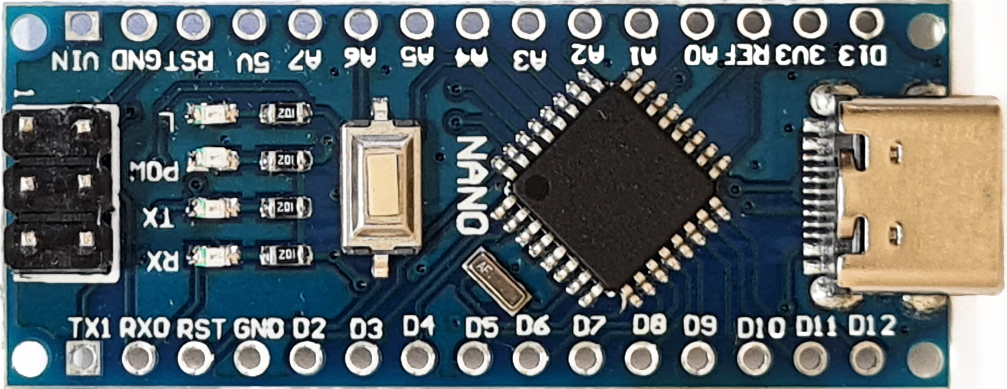
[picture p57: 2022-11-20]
WiringDiagram/Arduino.jpg

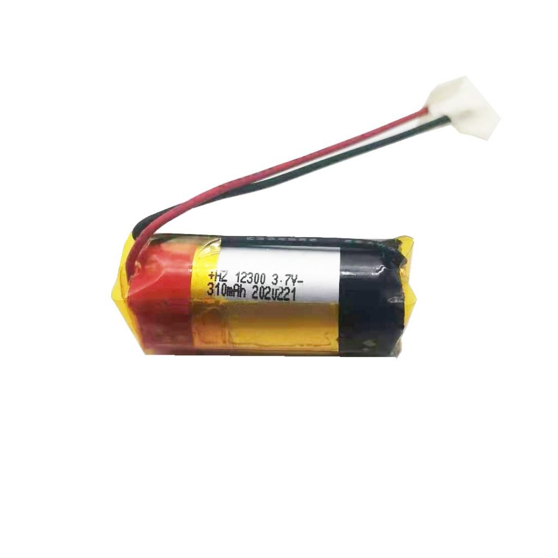
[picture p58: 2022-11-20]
WiringDiagram/Lipo.jpg

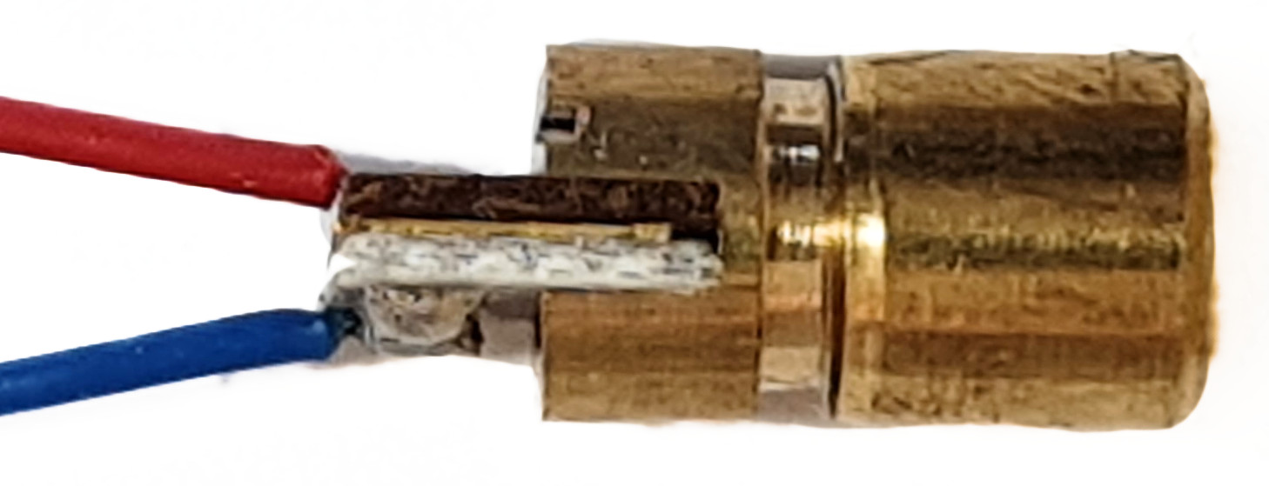
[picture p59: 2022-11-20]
WiringDiagram/Laser.jpg

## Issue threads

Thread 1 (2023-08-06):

Setup Pictures?

Xylopyrographer, 2023-08-06:
Hi. Wondering if you could post a few pictures or a diagram of the physical layout of the three lasers and photo receivers? Particularly curious about alignment when measuring focal plane curtain shutters. As well shielding of the receivers to avoid ambient light and laser cross-talk. Many thanks.

stuart-brown, 2023-08-08:
Hi, Thanks for the question. I built the tester using an old macro bellows and 3D printed parts. The lasers are held in a ball and sockets mount so they can be adjusted to shine into the photoreceptors. I intend to update the repo with the models and some photos, but I've been a bit busy with work and other things, so keep a watch on it.

stuart-brown, 2023-09-30:
Build details added to readme, together with STL files for 3D printed parts and lots of images

Closed 2023-09-30.

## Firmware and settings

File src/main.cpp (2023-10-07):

#include <Arduino.h>
#include <PinChangeInterrupt.h>

// When turned on all the timestamps and the results of
// the calculations are printed to the serial console
#define DEBUG 0

// choose which screen to use
// 0.96" OLED - connected via I2C
// 2.2"  TFT - connected via SPI
#define USE_OLED 0
#define USE_TFT 1

#if USE_OLED
#include "oled.h"
#endif

#if USE_TFT
#include "tft.h"
#endif

// pins for KY-008 Laser Diodes
#define LASER_DIODE_1_OUTPUT 5
#define LASER_DIODE_2_OUTPUT 6
#define LASER_DIODE_3_OUTPUT 7

// pins for ISO203 Laser Receivers
#define LASER_RECEIVER_1_INPUT 2
#define LASER_RECEIVER_2_INPUT 3
#define LASER_RECEIVER_3_INPUT 4

// variables set in interrupts
volatile uint32_t ts_1_start_us = 0;
volatile uint32_t ts_1_end_us = 0;
volatile bool speed_1_measured = false;
volatile bool curtain_1_measured = false;

volatile uint32_t ts_2_start_us = 0;
volatile uint32_t ts_2_end_us = 0;
volatile bool speed_2_measured = false;

volatile uint32_t ts_3_start_us = 0;
volatile uint32_t ts_3_end_us = 0;
volatile bool speed_3_measured = false;
volatile bool curtain_2_measured = false;

// variables for calculated values
double shutter_speed_1_ms = 0.0;
double shutter_speed_2_ms = 0.0;
double shutter_speed_3_ms = 0.0;
double fractional_shutter_speed_1 = 0.0;
double fractional_shutter_speed_2 = 0.0;
double fractional_shutter_speed_3 = 0.0;
double curtain_1_travel_time_ms = 0.0;
double curtain_2_travel_time_ms = 0.0;

// display update delay
#define DISPLAY_UPDATE_TRIGGER (UINT16_MAX / 2)
uint32_t display_update_counter = DISPLAY_UPDATE_TRIGGER;

//---------------------------------------------------
// Detector 1 interrupt handler
//---------------------------------------------------
void detector1(void)
{
  if (digitalRead(LASER_RECEIVER_1_INPUT))
  {
    ts_1_end_us = micros();
    speed_1_measured = true;
    curtain_1_measured = true;
  }
  else
  {
    ts_1_start_us = micros();
    speed_1_measured = false;
    curtain_1_measured = false;
  }
}

//---------------------------------------------------
// Detector 2 interrupt handler
//---------------------------------------------------
void detector2(void)
{
  if (digitalRead(LASER_RECEIVER_2_INPUT))
  {
    ts_2_end_us = micros();
    speed_2_measured = true;
  }
  else
  {
    ts_2_start_us = micros();
    speed_2_measured = false;
  }
}

//---------------------------------------------------
// Detector 3 interrupt handler
//---------------------------------------------------
void detector3(void)
{
  if (digitalRead(LASER_RECEIVER_3_INPUT))
  {
    ts_3_end_us = micros();
    speed_3_measured = true;
    curtain_2_measured = true;
  }
  else
  {
    ts_3_start_us = micros();
    speed_3_measured = false;
    curtain_2_measured = false;
  }
}

//---------------------------------------------------
// Setup function, called once at start
//---------------------------------------------------
void setup()
{
#if DEBUG
  Serial.begin(115200);
  Serial.flush();
#endif

  pinMode(LASER_RECEIVER_1_INPUT, INPUT);
  pinMode(LASER_RECEIVER_2_INPUT, INPUT);
  pinMode(LASER_RECEIVER_3_INPUT, INPUT);

  pinMode(LASER_DIODE_1_OUTPUT, OUTPUT);
  pinMode(LASER_DIODE_2_OUTPUT, OUTPUT);
  pinMode(LASER_DIODE_3_OUTPUT, OUTPUT);

#if USE_OLED
#if DEBUG
  Serial.println("Setup OLED");
#endif
  oled_setup();
#endif

#if USE_TFT
#if DEBUG
  Serial.println("Setup TFT");
#endif
  tft_setup();
#endif

// setup interrupts for the laser receivers
#if DEBUG
  Serial.println("Installing interrupt handlers");
#endif
  attachPCINT(digitalPinToPCINT(LASER_RECEIVER_1_INPUT), detector1, CHANGE);
  attachPCINT(digitalPinToPCINT(LASER_RECEIVER_2_INPUT), detector2, CHANGE);
  attachPCINT(digitalPinToPCINT(LASER_RECEIVER_3_INPUT), detector3, CHANGE);

#if DEBUG
  Serial.println("Ready... turning on lasers!");
#endif
  digitalWrite(LASER_DIODE_1_OUTPUT, HIGH);
  digitalWrite(LASER_DIODE_2_OUTPUT, HIGH);
  digitalWrite(LASER_DIODE_3_OUTPUT, HIGH);
}

//---------------------------------------------------
// Loop function, called repeatedly while running
//---------------------------------------------------
void loop()
{
  // --------- calculate ---------

  // Calculate shutter speeds independently so that a single sensor can
  // be used to measure only shutter speed or all 3 to measure shutter
  // speed and curtain travel with out needing a mode change switch
  //
  //           S3      S2      S1
  //            +       +       +
  //       ---------------+   +-------------------
  //                      |   |
  //          Curtain 1   |   |   Curtain 2
  //           Leading    |   |    Trailing
  //         <----------  |   |  <----------
  //                      |   |
  //       ---------------+   +-------------------
  //
  //            +----------------------+
  //            |                      |
  //   S1 ------+                      +--------------------------
  //            .       +----------------------+
  //            .       |              .       |
  //   S2 --------------+              .       +------------------
  //            .       .       +----------------------+
  //            .       .       |      .       .       |
  //   S3 ----------------------+      .       .       +----------
  //            .       .       .      .       .       .
  //            .       .       .      .       .       .
  //            .       .       .      .       .       .
  //            |<------------->|      .       .       .
  //            |   t_1_delta   |      .       .       .
  //        ts_1_start  .   ts_3_start .       .       .
  //                    .              .       .       .
  //                    .              .       .       .
  //                    |<-------------------->|       .
  //                    |       t_2_delta      |       .
  //              ts_2_start           .   ts_2_end    .
  //                                   .               .
  //                                   .               .
  //                                   |<------------->|
  //                                   |   t_3_delta   |
  //                                ts_1_end        ts_3_end
  //
  //   Curtain 1 travel time = t_1_delta
  //   Curtain 2 travel time = t_3_delta
  //   Shutter speed = t_2_delta
  //
  if (speed_1_measured)
  {
    speed_1_measured = false;
    display_update_counter = 0;
    double shutter_speed_us = (double)(ts_1_end_us - ts_1_start_us);
    shutter_speed_1_ms = shutter_speed_us / 1000.0;
    fractional_shutter_speed_1 = 1000000.0 / shutter_speed_us;
#if DEBUG
    Serial.print("t1_s=");
    Serial.print(ts_1_start_us);
    Serial.print("us   t1_e=");
    Serial.print(ts_1_end_us);
    Serial.println("us");
    Serial.print("Speed 1 = ");
    Serial.print(shutter_speed_1_ms, 1);
    Serial.println(" ms");
    Serial.print("Fractional Speed 1 = 1/");
    Serial.println(fractional_shutter_speed_1, 1);
#endif
  }
  if (speed_2_measured)
  {
    speed_2_measured = false;
    display_update_counter = 0;
    double shutter_speed_us = (double)(ts_2_end_us - ts_2_start_us);
    shutter_speed_2_ms = shutter_speed_us / 1000.0;
    fractional_shutter_speed_2 = 1000000.0 / shutter_speed_us;
#if DEBUG
    Serial.print("t2_s=");
    Serial.print(ts_2_start_us);
    Serial.print("us   t2_e=");
    Serial.print(ts_2_end_us);
    Serial.println("us");
    Serial.print("Speed 2 = ");
    Serial.print(shutter_speed_2_ms, 1);
    Serial.println(" ms");
    Serial.print("Fractional Speed 2 = 1/");
    Serial.println(fractional_shutter_speed_2, 1);
    Serial.println("");
#endif
  }
  if (speed_3_measured)
  {
    speed_3_measured = false;
    display_update_counter = 0;
    double shutter_speed_us = (double)(ts_3_end_us - ts_3_start_us);
    shutter_speed_3_ms = shutter_speed_us / 1000.0;
    fractional_shutter_speed_3 = 1000000.0 / shutter_speed_us;
#if DEBUG
    Serial.print("t3_s=");
    Serial.print(ts_3_start_us);
    Serial.print("us   t3_e=");
    Serial.print(ts_3_end_us);
    Serial.println("us");
    Serial.print("Speed 3 = ");
    Serial.print(shutter_speed_3_ms, 1);
    Serial.println(" ms");
    Serial.print("Fractional Speed 3 = 1/");
    Serial.println(fractional_shutter_speed_3, 1);
    Serial.println("");
#endif
  }
  if (curtain_1_measured && curtain_2_measured)
  {
    curtain_1_measured = false;
    curtain_2_measured = false;
    display_update_counter = 0;
    // check which is bigger and calculate accordingly
    // so that travel direction does not matter
    if (ts_3_start_us > ts_1_start_us)
    {
      curtain_1_travel_time_ms = (double)(ts_3_start_us - ts_1_start_us) / 1000.0;
    }
    else
    {
      curtain_1_travel_time_ms = (double)(ts_1_start_us - ts_3_start_us) / 1000.0;
    }
    if (ts_3_end_us > ts_1_end_us)
    {
      curtain_2_travel_time_ms = (double)(ts_3_end_us - ts_1_end_us) / 1000.0;
    }
    else
    {
      curtain_2_travel_time_ms = (double)(ts_1_end_us - ts_3_end_us) / 1000.0;
    }

#if DEBUG
    Serial.print("Curtain 1 travel time=");
    Serial.print(curtain_1_travel_time_ms, 1);
    Serial.println(" ms");

    Serial.print("Curtain 2 travel time=");
    Serial.print(curtain_2_travel_time_ms, 1);
    Serial.println(" ms");

    Serial.println("");
#endif
  }

  // --------- display ---------
  if (display_update_counter == DISPLAY_UPDATE_TRIGGER)
  {
#if USE_OLED
    oled_show_values(shutter_speed_1_ms,
                     shutter_speed_2_ms,
                     shutter_speed_3_ms,
                     fractional_shutter_speed_1,
                     fractional_shutter_speed_2,
                     fractional_shutter_speed_3,
                     curtain_1_travel_time_ms,
                     curtain_2_travel_time_ms);
#endif

#if USE_TFT
    tft_show_values(shutter_speed_1_ms,
                    shutter_speed_2_ms,
                    shutter_speed_3_ms,
                    fractional_shutter_speed_1,
                    fractional_shutter_speed_2,
                    fractional_shutter_speed_3,
                    curtain_1_travel_time_ms,
                    curtain_2_travel_time_ms);
#endif
  }
  if (display_update_counter <= DISPLAY_UPDATE_TRIGGER)
  {
    display_update_counter++;
  }
}

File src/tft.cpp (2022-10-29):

#include <SPI.h>               // TFT display connected via SPI
#include <Adafruit_ILI9341.h>  // Adafruit ILI9341 TFT library
#include <Adafruit_GFX.h>      // include Adafruit graphics library

#include "tft.h"
#include "version.h"

//  +-----------------------------------------------------------+
//  |                       Name (version)                      | <-- Version Text
//  |-----------------------------------------------------------|
//  |                       Shutter Speed                       | <-- Heading Text
//  |-------------------+-------------------+-------------------|
//  |                   |                   |                   |
//  |         1         |         1         |         1         | <-- Main Speed Text for center speed
//  |      -------      |      -------      |      -------      |     Minor Speed Text for edge speeds
//  |       xxx.x       |       xxx.x       |       xxx.x       | 
//  |                   |                   |                   |
//  |      xx.x ms      |      xx.x ms      |      xx.x ms      | <-- Minor Speed Text
//  |                   |                   |                   |
//  |-------------------+-------------------+-------------------|
//  |                    Curtain travel time                    | <-- Heading Text
//  |------------------------------+----------------------------|
//  |                              |                            |
//  |            yyy.y ms          |          yyy.y ms          | <-- Travel Time Text
//  |                              |                            |
//  +-----------------------------------------------------------+
//
#define SCREEN_WIDTH_px  320 // display width, in pixels
#define SCREEN_HEIGHT_px 240 // display height, in pixels

// Text sizes
// size 1 is 6 x 8 pixels (w x h)
// size 2 is 12 x 16 pixels viz 2 x size 1
// size 3 is 18 x 24 pixels viz 3 x size 1
#define BASE_TEXT_WIDTH_px       6
#define BASE_TEXT_HEIGHT_px      8

#define VERSION_TEXT_SIZE        1
#define HEADING_TEXT_SIZE        2
#define MINOR_SPEED_TEXT_SIZE    2
#define MAIN_SPEED_TEXT_SIZE     5
#define TRAVEL_TIME_TEXT_SIZE    3

// Positions
// These define the center top of each piece of text
// or the edges of heading boxes

// the space between two lines of text or text and borders
#define LINE_SPACE 6

// App name & Version text
#define VERSION_X                     (SCREEN_WIDTH_px/2)
#define VERSION_Y                     (LINE_SPACE)

// Box around "Shutter Speed" heading 
#define SHUTTER_SPEED_HEADING_LEFT    0
#define SHUTTER_SPEED_HEADING_RIGHT   (SCREEN_WIDTH_px)
#define SHUTTER_SPEED_HEADING_TOP     (VERSION_TEXT_SIZE*BASE_TEXT_HEIGHT_px+LINE_SPACE*2)
#define SHUTTER_SPEED_HEADING_BOTTOM  (SHUTTER_SPEED_HEADING_TOP+HEADING_TEXT_SIZE*BASE_TEXT_HEIGHT_px+LINE_SPACE*2)

// "Shutter Speed" heading
#define SHUTTER_SPEED_HEADING_X       ((SHUTTER_SPEED_HEADING_RIGHT-SHUTTER_SPEED_HEADING_LEFT)/2)
#define SHUTTER_SPEED_HEADING_Y       (SHUTTER_SPEED_HEADING_TOP+LINE_SPACE)

// Main shutter speed (centered)
#define MAIN_SPEED_X                  (SCREEN_WIDTH_px/2)
#define MAIN_SPEED_NUMERATOR_Y        (SHUTTER_SPEED_HEADING_BOTTOM + LINE_SPACE)
#define SPEED_FRACTION_LINE_Y         (MAIN_SPEED_NUMERATOR_Y+MAIN_SPEED_TEXT_SIZE*BASE_TEXT_HEIGHT_px+LINE_SPACE/2)
#define SPEED_DENOMINATOR_Y           (SPEED_FRACTION_LINE_Y+LINE_SPACE/2)
#define MAIN_SPEED_FRACTION_LINE_W    (MAIN_SPEED_TEXT_SIZE*BASE_TEXT_WIDTH_px*4)
#define MINOR_SPEED_FRACTION_LINE_W   (MINOR_SPEED_TEXT_SIZE*BASE_TEXT_WIDTH_px*4)

// Minor shutter speed, left & right - aligned to main shutter speed vertically
#define MINOR_SPEED_LEFT_X            (SCREEN_WIDTH_px*3/16)
#define MINOR_SPEED_RIGHT_X           (SCREEN_WIDTH_px*13/16)
#define MINOR_SPEED_NUMERATOR_Y       (SPEED_FRACTION_LINE_Y-LINE_SPACE/2-MINOR_SPEED_TEXT_SIZE*BASE_TEXT_HEIGHT_px)

// "Curtain Travel Time" heading box
#define TRAVEL_TIME_HEADING_LEFT      0
#define TRAVEL_TIME_HEADING_RIGHT     (SCREEN_WIDTH_px)
#define TRAVEL_TIME_HEADING_TOP       (SCREEN_HEIGHT_px-TRAVEL_TIME_TEXT_SIZE*BASE_TEXT_HEIGHT_px-HEADING_TEXT_SIZE*BASE_TEXT_HEIGHT_px-4*LINE_SPACE)
#define TRAVEL_TIME_HEADING_BOTTOM    (TRAVEL_TIME_HEADING_TOP+HEADING_TEXT_SIZE*BASE_TEXT_HEIGHT_px+LINE_SPACE*2)

// The measured times used to calculate shutter speeds
#define SHUTTER_TIME_Y                (TRAVEL_TIME_HEADING_TOP - MINOR_SPEED_TEXT_SIZE * BASE_TEXT_HEIGHT_px - LINE_SPACE)

// "Curtain Travel Time" heading
#define TRAVEL_TIME_HEADING_X         ((TRAVEL_TIME_HEADING_RIGHT-TRAVEL_TIME_HEADING_LEFT)/2)
#define TRAVEL_TIME_HEADING_Y         (TRAVEL_TIME_HEADING_TOP+LINE_SPACE)

// Travel time
#define TRAVEL_TIME_Y                 (TRAVEL_TIME_HEADING_BOTTOM + LINE_SPACE)

// Colours
#define BACKGROUND_COLOUR ILI9341_BLACK
#define TEXT_COLOUR       ILI9341_WHITE
#define HEADING_COLOUR    ILI9341_DARKCYAN
#define BORDER_COLOUR     ILI9341_WHITE

// pins for ILI9341 TFT display connected to hardware SPI
#define TFT_CS    8      // TFT CS  pin is connected to arduino pin 8
#define TFT_RST   9      // TFT RST pin is connected to arduino pin 9
#define TFT_DC    10     // TFT DC  pin is connected to arduino pin 10
#define TFT_MOSI  11     // SPI MOSI 
#define TFT_SCLK  13     // SPI Clock
#define TFT_MISO  12     // SPI MISO - is not used, 

// initialize ILI9341 TFT library
Adafruit_ILI9341 tft = Adafruit_ILI9341(TFT_CS, TFT_DC, TFT_RST); // ILI9341 driver with hardware SPI using the default SPI peripheral
//Adafruit_ILI9341 tft = Adafruit_ILI9341(TFT_CS, TFT_DC, TFT_MOSI, TFT_SCLK, TFT_RST, TFT_MISO); // ILI9341 driver with Software SPI
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

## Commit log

2022-10-29 Add a reference to the shutter speed tester calibration device project into README.md
2022-10-29 Add picture of laser diode to README.md
2022-10-29 Update path for laser diode image in README.md
2022-10-29 Switch to html markup for images in README.md
2022-10-29 Add datasheets, photos and details of Laser Diode & Laser Detector and information about them in README.md
2022-11-02 Make laser receiver images in README.md larger
2022-11-20 Add a wiring diagram
2023-09-30 Add details of mechanical build, including STL files and photographs.
    [13400 attery.stl, 2.2 inch TFT Display.stl, 35mm Film Frame.stl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]
2023-10-07 Remove toggling of inbuilt LED in interrupt handler, was added for debugging and not needed anymore
2023-10-07 README uodates: Add details about battery indicator & original OLED. Add headline image
2023-10-07 Fix typo in oled.cpp
    [oled.cpp]
